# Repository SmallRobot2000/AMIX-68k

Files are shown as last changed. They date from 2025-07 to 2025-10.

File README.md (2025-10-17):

# AMIX-68k
This is my Motorola 68010 CPU based system.
I plan to make it with 68010 CPU @ 12Mhz, DMA(68450) and othere periferials @ 10Mhz, IDE disk (CF card or good old HDD), Video output (Xosera), Aduio output (Aslo Xosera), Timers (again Xosera and 68230), Keyboard (68230 with RC2014 Yellow series MSX style keyboard), UART (16550 @ 115200 bps)

This isn't my first or (hopefully)last Retro style computer system, I alredy made two 6502 based computers, 8088 based system that is IBM compatable with 8 bit ISA, and built and coded for a handfull of z80/z180 based systems, mostly two RC2014 (Its funny that i like z80 MUCH more than 6502 but never made a system araund z80).
And also have ZX Spectrum 48k and ZX Spectrum NEXT.

But somehow this is the first time working with 68k chip, I known for 68k style systems but was afraid to touch them because they are two times more complex thatn 8 bit(right?) especely when i made 8088 system that was 8/16 bit and coudnt think how complecated would a full 16 bit system be, but when i looked closer at Motorola 68000 i thought i steped in to heven because of all the documentation and datasheet, and how a SINGLE datasheet was enough to understand almost everything to know(looking at you Intel).

# SPECS

|CPU | Motorola 68010 @ 12Mhz|
|----|---|
|RAM | 2 MB SRAM (Maybe DRAM in future)
|DMA | 68450 @ 10 Mhz|
|VIDEO & AUDIO| Xosera 640x480 2 playfields and Copper ( ͡❛ ͜ʖ ͡❛)|
|Keyboard| RC2014 Yellow series MSX style keyboard with n key rollover|
|DISK| IDE interface CF card or clasic HDD|
|UART| 16550 @ 18.432 Mhz -> 115200 bps|
|POWER| ATX PSU or 12V in|
|TIME & TIMERS| Tmers in Xosera and 68230, and RTC (SparkFun BOB-10160)|

# Present
All important stuff in kernel is done, now its time to make a unix like shell inside the kernel, later I will make it a executable file
All executables are in ELF file format, scripts are not yet suported nether are pipes and redirects.
# Future (TODO)

 - Add working permissions and thus users
 - Shell as executable not built in kenrel
 - Support for pipes and redirects
 - Move keyboard to a new process and make it all in C because now it sometimes glitches
 - Clean up code and make more flexiable(cariables insted of defines)
 - Move some stuff to files like history and $PATH etc.
 - Add global sbrk with suport for freeing all alocations per process when killed
 - When poritng keyboard to C add some shortcuts
 - add system specific command something similar to symctl
 - add Ethernet as expantion

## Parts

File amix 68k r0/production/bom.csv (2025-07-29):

Designator | Footprint | Quantity | Value | LCSC Part #
C1 | CP_Radial_D5.0mm_P2.50mm | 1 | 10uF
C10, C11, C12, C13, C14, C15, C16, C17, C18, C21, C22, C23, C24, C25, C26, C27, C28, C29, C30, C31, C32, C8, C9 | C_Rect_L4.0mm_W2.5mm_P2.50mm | 23 | 100nF
C19 | CP_Radial_D5.0mm_P2.50mm | 1 | 100uF
C2 | C_Rect_L4.0mm_W2.5mm_P2.50mm | 1 | 1uF
C20 | CP_Radial_D6.3mm_P2.50mm | 1 | 220uF
C3, C5, C7 | CP_Radial_D5.0mm_P2.50mm | 3 | 10uF
C33, C4, C6 | CP_Radial_D5.0mm_P2.50mm | 3 | 1uF(2.2uF real)
D1, D2 | D_DO-35_SOD27_P7.62mm_Horizontal | 2 | D
D10 | LED_D4.0mm | 1 | LED_+5
D11 | LED_D4.0mm | 1 | LED_+5SB
D12 | LED_D4.0mm | 1 | LED_-12
D3, D4, D5, D6 | LED_D4.0mm | 4 | LED
D7, D8 | D_DO-35_SOD27_P7.62mm_Horizontal | 2 | 1N4148
D9 | LED_D4.0mm | 1 | LED_+12
HOLE1, HOLE2, HOLE3, HOLE4, HOLE5, HOLE6, HOLE7 | Hole_3mm | 7 | HOLE
IC1, IC2, IC3 | DIP-20_W7.62mm_Socket_LongPads | 3 | 74HCT245
J1 | PinHeader_1x03_P2.54mm_Vertical | 1 | BG
J10 | PinSocket_2x06_P2.54mm_Horizontal | 1 | PMOD_BOTTOM
J11, J12, J15, J27 | PinHeader_1x04_P2.54mm_Vertical | 4 | Conn_01x04_Pin
J13 | PinHeader_1x07_P2.54mm_Vertical | 1 | RTC (SparkFun BOB-10160)
J14 | USB_B_Lumberg_2411_02_Horizontal | 1 | USB_B
J16 | Molex_Mini-Fit_Jr_5566-24A2_2x12_P4.20mm_Vertical | 1 | ATX-24 - IF NO 12V in
J17 | BarrelJack_Horizontal | 1 | 12V in if NO ATX
J18 | IDC-Header_2x20_P2.54mm_Vertical | 1 | IDE 40 pin
J19 | PinHeader_1x02_P2.54mm_Vertical | 1 | ExtPWRON
J2 | PinHeader_1x03_P2.54mm_Vertical | 1 | FCx
J20 | PinHeader_1x02_P2.54mm_Vertical | 1 | PWR_LED
J21 | IDC-Header_2x08_P2.54mm_Vertical | 1 | Conn_02x08_Odd_Even
J22 | PinHeader_1x12_P2.54mm_Vertical | 1 | PPI
J23, J24 | PinHeader_1x08_P2.54mm_Vertical | 2 | Conn_01x08_Pin
J25, J26 | PinHeader_2x04_P2.54mm_Vertical | 2 | Conn_02x04_Odd_Even
J28 | PinSocket_2x32_P2.54mm_Horizontal | 1 | Conn_02x32_Odd_Even
J29 | PinHeader_1x02_P2.54mm_Vertical | 1 | NMI
J3 | PinHeader_1x03_P2.54mm_Vertical | 1 | PRF
J4 | PinHeader_1x02_P2.54mm_Vertical | 1 | BUS_STAT
J5 | PinHeader_1x02_P2.54mm_Vertical | 1 | HLT and RESET
J6 | PinHeader_1x24_P2.54mm_Vertical | 1 | Upduino_LHS
J7 | PinHeader_1x24_P2.54mm_Vertical | 1 | Upduino_RHS
J8 | PinHeader_1x06_P2.54mm_Vertical | 1 | Conn_01x06_Pin
J9 | PinSocket_2x06_P2.54mm_Horizontal | 1 | PMOD_TOP
JP1, JP2, JP21, JP8 | PinHeader_1x02_P2.54mm_Vertical | 4 | Jumper_2_Open
JP10, JP11 | PinHeader_1x02_P2.54mm_Vertical | 2 | Close only if NO ATX
JP14, JP15 | PinHeader_1x02_P2.54mm_Vertical | 2 | DTACK ctrl 0
JP16 | PinHeader_1x02_P2.54mm_Vertical | 1 | DMAAC_REQ0 = IDE
JP17 | PinHeader_1x02_P2.54mm_Vertical | 1 | DMAAC_ACK0 = IDE
JP18, JP20 | PinHeader_1x02_P2.54mm_Vertical | 2 | Jumper_2_Bridged
JP3, JP4, JP5, JP6 | PinHeader_1x02_P2.54mm_Vertical | 4 | Jumper
Q1, Q2 | TO-92_Inline | 2 | 2N3904
R1, R14, R15, R17, R2 | R_Axial_DIN0207_L6.3mm_D2.5mm_P10.16mm_Horizontal | 5 | 1k
R10, R11, R12, R5, R6, R7, R8, R9 | R_Axial_DIN0207_L6.3mm_D2.5mm_P10.16mm_Horizontal | 8 | 100
R13, R24 | R_Axial_DIN0207_L6.3mm_D2.5mm_P10.16mm_Horizontal | 2 | 150k
R16, R18, R19, R20, R21, R22, R3, R30, R4 | R_Axial_DIN0207_L6.3mm_D2.5mm_P10.16mm_Horizontal | 9 | 10k
R23 | R_Axial_DIN0207_L6.3mm_D2.5mm_P10.16mm_Horizontal | 1 | 470
R25, R26 | R_Axial_DIN0207_L6.3mm_D2.5mm_P10.16mm_Horizontal | 2 | 680
R27, R28, R29 | R_Axial_DIN0207_L6.3mm_D2.5mm_P10.16mm_Horizontal | 3 | 330
RN1, RN2, RN3, RN4 | R_Array_SIP8 | 4 | R_Network07
SW1 | SW_PUSH_6mm | 1 | Reset
SW3 | SW_Slide_SPDT_Angled_CK_OS102011MA1Q | 1 | SW_SPDT
U1 | DIP-64_W22.86mm_Socket_LongPads | 1 | MC68010P
U10, U11, U12, U3 | DIP-20_W7.62mm_Socket_LongPads | 4 | GAL16V8
U13 | DIP-40_W15.24mm_Socket_LongPads | 1 | 16550
U14 | SSOP-28_5.3x10.2mm_P0.65mm | 1 | FT232RL
U15 | TO-220-3_Horizontal_TabDown | 1 | LM7805_TO220
U16, U28 | DIP-14_W7.62mm_Socket_LongPads | 2 | 74HC74
U17 | TO-220-3_Horizontal_TabDown | 1 | LM1117T-3.3
U18 | DIP-64_W22.86mm_Socket_LongPads | 1 | MC68450
U19, U20, U21 | DIP-20_W7.62mm_Socket_LongPads | 3 | 74HC245
U2, U27 | DIP-14_W7.62mm_Socket_LongPads | 2 | 74HC14
U22, U23 | DIP-20_W7.62mm_Socket_LongPads | 2 | 74HC373
U24 | DIP-14_W7.62mm_Socket_LongPads | 1 | 74LS32
U25 | DIP-16_W7.62mm_Socket_LongPads | 1 | 74LS148
U26 | DIP-48_W15.24mm_Socket_LongPads | 1 | 68230
U4, U5, U6, U7 | DIP-32_W15.24mm_Socket_LongPads | 4 | AS6C4008-55PCN
U8, U9 | DIP_Socket-32_W11.9_W12.7_W15.24_W17.78_W18.5_3M_232-1285-00-0602J | 2 | SST39SF040
Y1 | Oscillator_DIP-14 | 1 | 1.8432Mhz
Y3 | Oscillator_DIP-14 | 1 | 12Mhz
Y5 | Oscillator_DIP-14 | 1 | 10Mhz
Mouser
Mix

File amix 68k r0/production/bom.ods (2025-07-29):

Designator | Footprint | Quantity | Value | Mouser Part # | Socket*
C1 | CP_Radial_D5.0mm_P2.50mm | 1 | 10uF | 667-ECA-1CM100I
C10, C11, C12, C13, C14, C15, C16, C17, C18, C21, C22, C23, C24, C25, C26, C27, C28, C29, C30, C31, C32, C8, C9 | C_Rect_L4.0mm_W2.5mm_P2.50mm | 23 | 100nF | 594-K104K15X7RF53L2
C19 | CP_Radial_D5.0mm_P2.50mm | 1 | 100uF | 667-ECA-0JM101I
C2 | C_Rect_L4.0mm_W2.5mm_P2.50mm | 1 | 1uF | 810-FG18X7R1E105KRT6
C20 | CP_Radial_D6.3mm_P2.50mm | 1 | 220uF | 667-EEU-FC1A221SB
C3, C5, C7 | CP_Radial_D5.0mm_P2.50mm | 3 | 10uF | 667-ECA-1CM100I
C33, C4, C6 | CP_Radial_D5.0mm_P2.50mm | 3 | 1uF(2.2uF real) | 667-ECA-1HHG2R2I
D1, D2 | D_DO-35_SOD27_P7.62mm_Horizontal | 2 | D | 512-1N4148
D10 | LED_D4.0mm | 1 | LED_+5 | 630-HLMP-LG75-XY0DD
D11 | LED_D4.0mm | 1 | LED_+5SB | 630-HLMP-LG75-XY0DD
D12 | LED_D4.0mm | 1 | LED_-12 | 630-HLMP-LG75-XY0DD
D3, D4, D5, D6 | LED_D4.0mm | 4 | LED | 630-HLMP-LB65-RU0DD
D7, D8 | D_DO-35_SOD27_P7.62mm_Horizontal | 2 | 1N4148 | 512-1N4148
D9 | LED_D4.0mm | 1 | LED_+12 | 630-HLMP-LG75-XY0DD
HOLE1, HOLE2, HOLE3, HOLE4, HOLE5, HOLE6, HOLE7 | Hole_3mm | 7 | HOLE | NaN
IC1, IC2, IC3 | DIP-20_W7.62mm_Socket_LongPads | 3 | 74HCT245 | 595-SN74HCT245N | 571-1-2199298-6
J1 | PinHeader_1x03_P2.54mm_Vertical | 1 | BG | 200-TSW14023TS
J10 | PinSocket_2x06_P2.54mm_Horizontal | 1 | PMOD_BOTTOM | 710-613012243121
J11, J12, J15, J27 | PinHeader_1x04_P2.54mm_Vertical | 4 | Conn_01x04_Pin | 200-TSW14023TS
J13 | PinHeader_1x07_P2.54mm_Vertical | 1 | RTC (SparkFun BOB-10160) | 710-61304011021 | 872-920-0215-01
J14 | USB_B_Lumberg_2411_02_Horizontal | 1 | USB_B | 179-UJ2-B-HR-G-TH
J16 | Molex_Mini-Fit_Jr_5566-24A2_2x12_P4.20mm_Vertical | 1 | ATX-24 - IF NO 12V in | 538-39-28-1243
J17 | BarrelJack_Horizontal | 1 | 12V in if NO ATX | 490-PJ-102A
J18 | IDC-Header_2x20_P2.54mm_Vertical | 1 | IDE 40 pin | 200-TST12003GD
J19 | PinHeader_1x02_P2.54mm_Vertical | 1 | ExtPWRON | 200-TSW14023TS
J2 | PinHeader_1x03_P2.54mm_Vertical | 1 | FCx | 200-TSW14023TS
J20 | PinHeader_1x02_P2.54mm_Vertical | 1 | PWR_LED | 200-TSW14023TS
J21 | IDC-Header_2x08_P2.54mm_Vertical | 1 | Conn_02x08_Odd_Even | 200-TST10802TD
J22 | PinHeader_1x12_P2.54mm_Vertical | 1 | PPI | 200-TSW14023TS
J23, J24 | PinHeader_1x08_P2.54mm_Vertical | 2 | Conn_01x08_Pin | 200-TSW14023TS
J25, J26 | PinHeader_2x04_P2.54mm_Vertical | 2 | Conn_02x04_Odd_Even | 523-G800LQ592032HR
J28 | PinSocket_2x32_P2.54mm_Horizontal | 1 | Conn_02x32_Odd_Even | 200-SSW13202TDRA
J29 | PinHeader_1x02_P2.54mm_Vertical | 1 | NMI | 200-TSW14023TS
J3 | PinHeader_1x03_P2.54mm_Vertical | 1 | PRF | 200-TSW14023TS
J4 | PinHeader_1x02_P2.54mm_Vertical | 1 | BUS_STAT | 200-TSW14023TS
J5 | PinHeader_1x02_P2.54mm_Vertical | 1 | HLT and RESET | 200-TSW14023TS
J6 | PinHeader_1x24_P2.54mm_Vertical | 1 | Upduino_LHS | 200-BCS124FSTE
J7 | PinHeader_1x24_P2.54mm_Vertical | 1 | Upduino_RHS | 200-BCS124FSTE
J8 | PinHeader_1x06_P2.54mm_Vertical | 1 | Conn_01x06_Pin | 200-TSW14023TS
J9 | PinSocket_2x06_P2.54mm_Horizontal | 1 | PMOD_TOP | 710-613012243121
JP1, JP2, JP21, JP8 | PinHeader_1x02_P2.54mm_Vertical | 4 | Jumper_2_Open | 200-TSW14023TS
JP10, JP11 | PinHeader_1x02_P2.54mm_Vertical | 2 | Close only if NO ATX | 200-TSW14023TS
JP14, JP15 | PinHeader_1x02_P2.54mm_Vertical | 2 | DTACK ctrl 0 | 200-TSW14023TS
JP16 | PinHeader_1x02_P2.54mm_Vertical | 1 | DMAAC_REQ0 = IDE | 200-TSW14023TS
JP17 | PinHeader_1x02_P2.54mm_Vertical | 1 | DMAAC_ACK0 = IDE | 200-TSW14023TS
JP18, JP20 | PinHeader_1x02_P2.54mm_Vertical | 2 | Jumper_2_Bridged | 200-TSW14023TS
JP3, JP4, JP5, JP6 | PinHeader_1x02_P2.54mm_Vertical | 4 | Jumper | 200-TSW14023TS
Q1, Q2 | TO-92_Inline | 2 | 2N3904 | 637-2N3904
R1, R14, R15, R17, R2 | R_Axial_DIN0207_L6.3mm_D2.5mm_P10.16mm_Horizontal | 5 | 1k | 603-MF0207FRE52-1K
R10, R11, R12, R5, R6, R7, R8, R9 | R_Axial_DIN0207_L6.3mm_D2.5mm_P10.16mm_Horizontal | 8 | 100 | 603-MF0207FRE52-100R
R13, R24 | R_Axial_DIN0207_L6.3mm_D2.5mm_P10.16mm_Horizontal | 2 | 150k | 603-MF0207FTE52-150K
R16, R18, R19, R20, R21, R22, R3, R30, R4 | R_Axial_DIN0207_L6.3mm_D2.5mm_P10.16mm_Horizontal | 9 | 10k | 603-MF0207FRE52-10K
R23 | R_Axial_DIN0207_L6.3mm_D2.5mm_P10.16mm_Horizontal | 1 | 470 | 603-MF0207FRE52-470R
R25, R26 | R_Axial_DIN0207_L6.3mm_D2.5mm_P10.16mm_Horizontal | 2 | 680 | 603-MF0207FTE52-680R
R27, R28, R29 | R_Axial_DIN0207_L6.3mm_D2.5mm_P10.16mm_Horizontal | 3 | 330 | 603-MF0207FTE52-330R
RN1, RN2, RN3, RN4 | R_Array_SIP8 | 4 | R_Network07 | 652-4608X-101-103FLF
SW1 | SW_PUSH_6mm | 1 | Reset | 179-TS026680BK100SCR
SW3 | SW_Slide_SPDT_Angled_CK_OS102011MA1Q | 1 | SW_SPDT | 611-OS102011MA1QN1
U1 | DIP-64_W22.86mm_Socket_LongPads | 1 | MC68010P |  | 575-199964
U10, U11, U12, U3 | DIP-20_W7.62mm_Socket_LongPads | 4 | GAL16V8 | 556-AF16V8B15PU | 571-1-2199298-6
U13 | DIP-40_W15.24mm_Socket_LongPads | 1 | 16550
U14 | SSOP-28_5.3x10.2mm_P0.65mm | 1 | FT232RL | 895-FT232RNL-REEL
U15 | TO-220-3_Horizontal_TabDown | 1 | LM7805_TO220 | 926-LM7805CT/NOPB
U16, U28 | DIP-14_W7.62mm_Socket_LongPads | 2 | 74HC74 | 595-SN74HC74N | 571-1-2199298-3
U17 | TO-220-3_Horizontal_TabDown | 1 | LM1117T-3.3 | 926-LM1117T-3.3/NOPB
U18 | DIP-64_W22.86mm_Socket_LongPads | 1 | MC68450 |  | 575-199964
U19, U20, U21 | DIP-20_W7.62mm_Socket_LongPads | 3 | 74HC245 | 595-SN74HC245N | 571-1-2199298-6
U2, U27 | DIP-14_W7.62mm_Socket_LongPads | 2 | 74HC14 | 595-SN74HCT14N | 571-1-2199298-3
U22, U23 | DIP-20_W7.62mm_Socket_LongPads | 2 | 74HC373 | 595-SN74HCT373N | 571-1-2199298-6
U24 | DIP-14_W7.62mm_Socket_LongPads | 1 | 74LS32 | 595-SN74HC32N | 571-1-2199298-3
U25 | DIP-16_W7.62mm_Socket_LongPads | 1 | 74LS148 | 595-SN74HC148N | 571-1-2199298-4
U26 | DIP-48_W15.24mm_Socket_LongPads | 1 | 68230 |  | 575-1104764841001000
U4, U5, U6, U7 | DIP-32_W15.24mm_Socket_LongPads | 4 | AS6C4008-55PCN | 913-AS6C4008-55PIN | 571-1-2199300-2
U8, U9 | DIP_Socket-32_W11.9_W12.7_W15.24_W17.78_W18.5_3M_232-1285-00-0602J | 2 | SST39SF040 | 804-39SF0407CPHE | 535-32-6570-10
Y1 | Oscillator_DIP-14 | 1 | 1.8432Mhz/18.432 | 774-MXO45HS-3C-12.0 |  | 815-ACO-18.432-EK
Y3 | Oscillator_DIP-14 | 1 | 12Mhz | 774-MXO45HS-3C-12.0 |  | 774-MXO45HS-3C-12.0, 520-TCF600-X
Y5 | Oscillator_DIP-14 | 1 | 10Mhz | 520-TCF1000-X |  | 520-TCF800-X
Mouser
Mix
Using old

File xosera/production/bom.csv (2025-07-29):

Designator | Footprint | Quantity | Value | LCSC Part #
C1, C10, C11, C2, C3, C4, C5, C6, C9 | C2.5-3 | 9 | 100nF
C7 | CP_Radial_D5.0mm_P2.50mm | 1 | 100uF
C8 | CP_Radial_D6.3mm_P2.50mm | 1 | 220uF
IC1, IC2, IC5 | DIP-20_W7.62mm_Socket_LongPads | 3 | 74HCT245
IC3 | DIP-20_W7.62mm_Socket_LongPads | 1 | ATF16V8BQL
IC4 | DIP-24_W7.62mm_LongPads | 1 | GAL22V10
IC6 | DIP-14_W7.62mm_Socket_LongPads | 1 | 74LS74
J1 | PinHeader_1x02_P2.54mm_Vertical | 1 | IOSEL/VPA
J2 | PinSocket_1x24_P2.54mm_Vertical | 1 | Upduino_LHS
J28 | PinSocket_2x32_P2.54mm_Horizontal | 1 | Conn_02x32_Odd_Even
J3 | PinSocket_1x24_P2.54mm_Vertical | 1 | Upduino_RHS
J4 | PinSocket_2x06_P2.54mm_Horizontal | 1 | PMOD_TOP
J5 | PinSocket_2x06_P2.54mm_Horizontal | 1 | PMOD_BOTTOM
J6 | PinHeader_1x06_P2.54mm_Vertical | 1 | Conn_01x06_Male
J7, J8 | PinHeader_2x04_P2.54mm_Vertical | 2 | Conn_02x04_Counter_Clockwise
JP1, JP3, JP4, JP5, JP6 | PinHeader_1x02_P2.54mm_Vertical | 5 | Jumper
JP2 | SolderJumper-2_P1.3mm_Open_Pad1.0x1.5mm | 1 | Jumper
JP7 | SolderJumper-2_P1.3mm_Open_Pad1.0x1.5mm | 1 | ~{IRQ5}
Q1 | TO-92_HandSolder | 1 | 2N3904
R1, R2, R3, R4, R5, R6, R7, R8 | R-0207_10 | 8 | R
R9 | R-0207_10 | 1 | 150K
TP1, TP2, TP3 | PinHeader_1x08_P2.54mm_Vertical | 3 | Conn_01x08_Male

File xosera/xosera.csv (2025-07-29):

Id | Designator | Package | Quantity | Designation | Supplier and ref
1 | J3 | PinSocket_1x24_P2.54mm_Vertical | 1 | Upduino_RHS
2 | IC4 | DIP-24_W7.62mm_LongPads | 1 | GAL22V10
3 | JP2 | SolderJumper-2_P1.3mm_Open_Pad1.0x1.5mm | 1 | Jumper
4 | REF** | MD-rosco_m68k_logo | 1 | MD-rosco_m68k_logo
5 | REF** | WEEE-Logo_4.2x6mm_SilkScreen | 1 | WEEE-Logo_4.2x6mm_SilkScreen
6 | REF** | RoHS-Logo_6mm_SilkScreen | 1 | RoHS-Logo_6mm_SilkScreen
7 | REF** | SM-rosco_m68k_logo | 1 | SM-rosco_m68k_logo
8 | J6 | PinHeader_1x06_P2.54mm_Vertical | 1 | Conn_01x06_Male
9 | JP6,JP5,JP4,JP3,JP1 | PinHeader_1x02_P2.54mm_Vertical | 5 | Jumper
10 | IC1,IC5,IC2 | DIP-20_W7.62mm_Socket_LongPads | 3 | 74HCT245
11 | Q1 | TO-92_HandSolder | 1 | 2N3904
12 | IC6 | DIP-14_W7.62mm_Socket_LongPads | 1 | 74LS74
13 | R9 | R-0207_10 | 1 | 150K
14 | J2 | PinSocket_1x24_P2.54mm_Vertical | 1 | Upduino_LHS
15 | TP3,TP2,TP1 | PinHeader_1x08_P2.54mm_Vertical | 3 | Conn_01x08_Male
16 | J1 | pin-2X32 | 1 | Conn_02x32_Odd_Even
17 | J5 | PinSocket_2x06_P2.54mm_Horizontal | 1 | PMOD_BOTTOM
18 | J4 | PinSocket_2x06_P2.54mm_Horizontal | 1 | PMOD_TOP
19 | C6,C11,C10,C9,C5,C4,C3,C2,C1 | C2.5-3 | 9 | 100nF
20 | R8,R7,R6,R5,R4,R3,R2,R1 | R-0207_10 | 8 | R
21 | J7,J8 | PinHeader_2x04_P2.54mm_Vertical | 2 | Conn_02x04_Counter_Clockwise
22 | IC3 | DIP-20_W7.62mm_Socket_LongPads | 1 | ATF16V8BQL
23 | C8 | CP_Radial_D6.3mm_P2.50mm | 1 | 220uF
24 | C7 | CP_Radial_D5.0mm_P2.50mm | 1 | 100uF

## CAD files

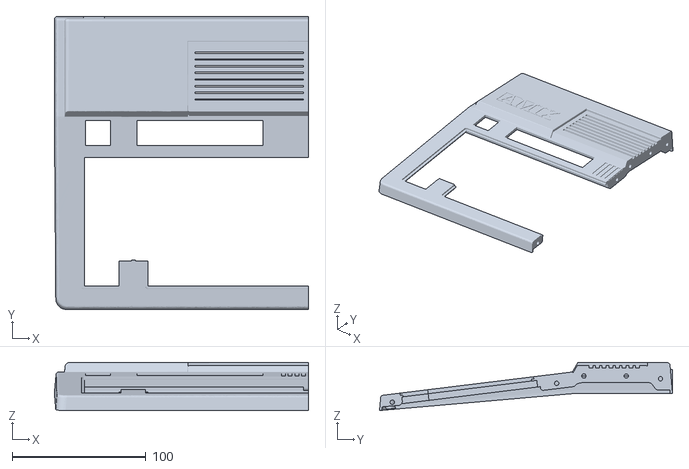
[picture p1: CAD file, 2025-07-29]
AMIX case/Top_left.stl
190.4 x 219.4 x 36.0

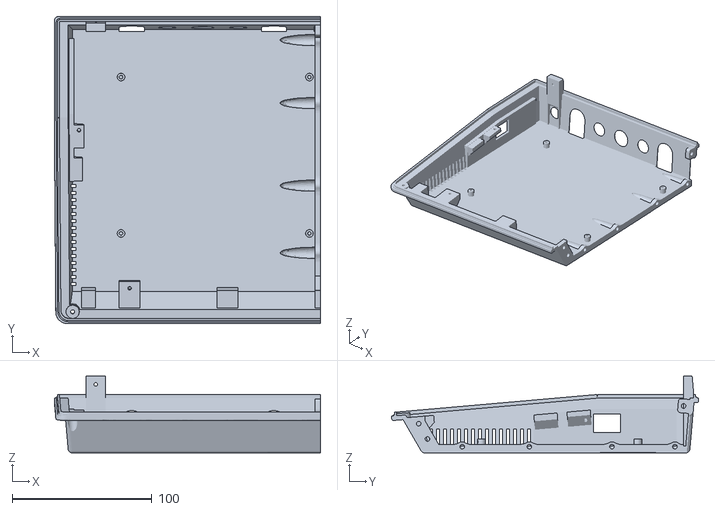
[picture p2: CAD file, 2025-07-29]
AMIX case/Bottom_left.stl
190.4 x 219.4 x 55.0

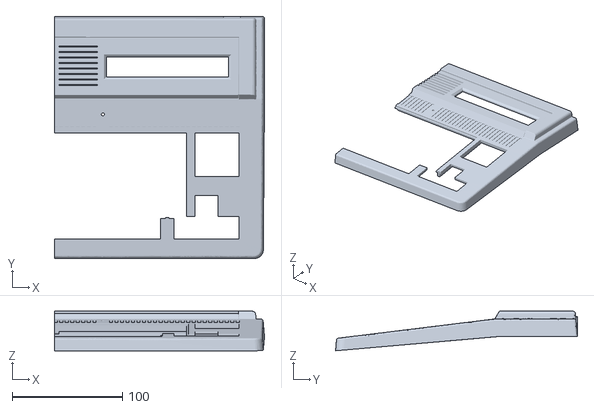
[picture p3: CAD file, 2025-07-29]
AMIX case/Top_right.stl
190.4 x 219.4 x 35.9

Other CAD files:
AMIX case/Bottom_right.stl

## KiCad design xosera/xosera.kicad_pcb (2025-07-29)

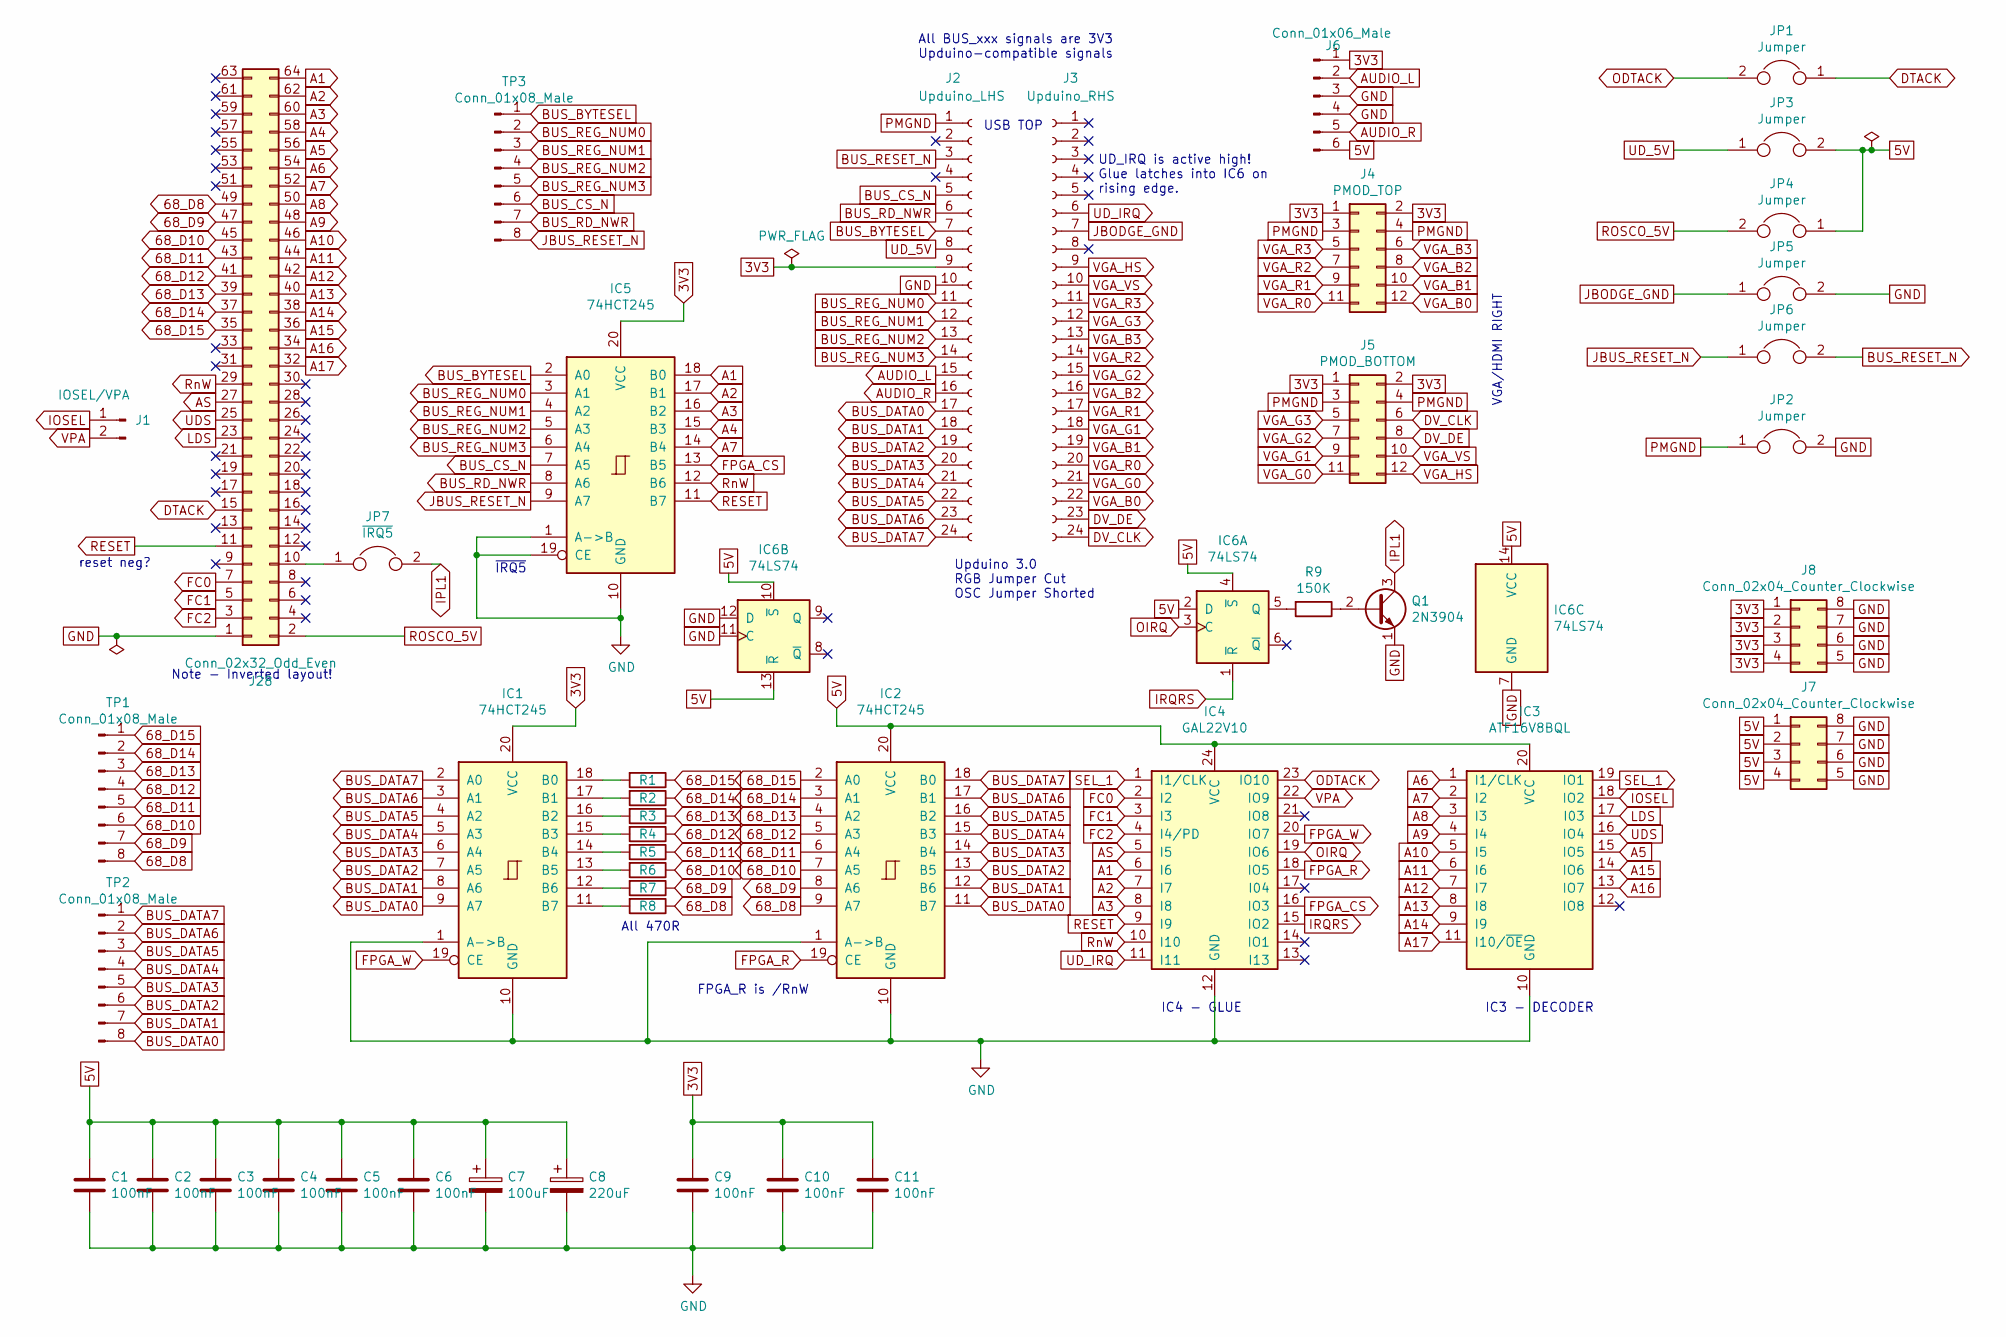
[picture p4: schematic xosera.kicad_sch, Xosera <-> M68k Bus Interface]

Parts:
C1, C2, C3, C4, C5, C6, C9, C10, C11: 100nF; C2.5-3
C7: 100uF; CP_Radial_D5.0mm_P2.50mm
C8: 220uF; CP_Radial_D6.3mm_P2.50mm
IC1, IC2, IC5: 74HCT245; DIP-20_W7.62mm_Socket_LongPads
IC3: ATF16V8BQL; DIP-20_W7.62mm_Socket_LongPads
IC4: GAL22V10; DIP-24_W7.62mm_LongPads
IC6: 74LS74; DIP-14_W7.62mm_Socket_LongPads
J1: IOSEL/VPA; PinHeader_1x02_P2.54mm_Vertical
J2: Upduino_LHS; PinSocket_1x24_P2.54mm_Vertical
J3: Upduino_RHS; PinSocket_1x24_P2.54mm_Vertical
J4: PMOD_TOP; PinSocket_2x06_P2.54mm_Horizontal
J5: PMOD_BOTTOM; PinSocket_2x06_P2.54mm_Horizontal
J6: Conn_01x06_Male; PinHeader_1x06_P2.54mm_Vertical
J7, J8: Conn_02x04_Counter_Clockwise; PinHeader_2x04_P2.54mm_Vertical
J28: Conn_02x32_Odd_Even; PinSocket_2x32_P2.54mm_Horizontal
JP1, JP3, JP4, JP5, JP6: Jumper; PinHeader_1x02_P2.54mm_Vertical
JP2: Jumper; SolderJumper-2_P1.3mm_Open_Pad1.0x1.5mm
JP7: ~{IRQ5}; SolderJumper-2_P1.3mm_Open_Pad1.0x1.5mm
Q1: 2N3904; TO-92_HandSolder
R1, R2, R3, R4, R5, R6, R7, R8: R; R-0207_10
R9: 150K; R-0207_10
TP1, TP2, TP3: Conn_01x08_Male; PinHeader_1x08_P2.54mm_Vertical

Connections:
3V3: C9.1, C10.1, C11.1, IC1.20 (VCC), IC5.20 (VCC), J2.9, J4.1, J4.2, J5.1, J5.2, J6.1, J8.1, J8.2, J8.3, J8.4
68_D8: IC2.9 (A7), J28.49, R8.1, TP1.8
68_D9: IC2.8 (A6), J28.47, R7.1, TP1.7
68_D10: IC2.7 (A5), J28.45, R6.1, TP1.6
68_D11: IC2.6 (A4), J28.43, R5.1, TP1.5
68_D12: IC2.5 (A3), J28.41, R4.1, TP1.4
68_D13: IC2.4 (A2), J28.39, R3.1, TP1.3
68_D14: IC2.3 (A1), J28.37, R2.1, TP1.2
68_D15: IC2.2 (A0), J28.35, R1.1, TP1.1
A1: IC4.6 (I6), IC5.18 (B0), J28.64
A2: IC4.7 (I7), IC5.17 (B1), J28.62
A3: IC4.8 (I8), IC5.16 (B2), J28.60
A4: IC5.15 (B3), J28.58
A5: IC3.15 (IO5), J28.56
A6: IC3.1 (I1/CLK), J28.54
A7: IC3.2 (I2), IC5.14 (B4), J28.52
A8: IC3.3 (I3), J28.50
A9: IC3.4 (I4), J28.48
A10: IC3.5 (I5), J28.46
A11: IC3.6 (I6), J28.44
A12: IC3.7 (I7), J28.42
A13: IC3.8 (I8), J28.40
A14: IC3.9 (I9), J28.38
A15: IC3.14 (IO6), J28.36
A16: IC3.13 (IO7), J28.34
A17: IC3.11 (I10/~OE), J28.32
AS: IC4.5 (I5), J28.27
AUDIO_L: J2.15, J6.2
AUDIO_R: J2.16, J6.5
BUS_BYTESEL: IC5.2 (A0), J2.7, TP3.1
BUS_CS_N: IC5.7 (A5), J2.5, TP3.6
BUS_DATA0: IC1.9 (A7), IC2.11 (B7), J2.17, TP2.8
BUS_DATA1: IC1.8 (A6), IC2.12 (B6), J2.18, TP2.7
BUS_DATA2: IC1.7 (A5), IC2.13 (B5), J2.19, TP2.6
BUS_DATA3: IC1.6 (A4), IC2.14 (B4), J2.20, TP2.5
BUS_DATA4: IC1.5 (A3), IC2.15 (B3), J2.21, TP2.4
BUS_DATA5: IC1.4 (A2), IC2.16 (B2), J2.22, TP2.3
BUS_DATA6: IC1.3 (A1), IC2.17 (B1), J2.23, TP2.2
BUS_DATA7: IC1.2 (A0), IC2.18 (B0), J2.24, TP2.1
BUS_RD_NWR: IC5.8 (A6), J2.6, TP3.7
BUS_REG_NUM0: IC5.3 (A1), J2.11, TP3.2
BUS_REG_NUM1: IC5.4 (A2), J2.12, TP3.3
BUS_REG_NUM2: IC5.5 (A3), J2.13, TP3.4
BUS_REG_NUM3: IC5.6 (A4), J2.14, TP3.5
BUS_RESET_N: J2.3, JP6.2
DTACK: J28.15, JP1.1
DV_CLK: J3.24, J5.6
DV_DE: J3.23, J5.8
FC0: IC4.2 (I2), J28.7
FC1: IC4.3 (I3), J28.5
FC2: IC4.4 (I4/PD), J28.3
FPGA_CS: IC4.16 (IO3), IC5.13 (B5)
FPGA_R: IC2.19 (CE), IC4.18 (IO5)
FPGA_W: IC1.19 (CE), IC4.20 (IO7)
IOSEL: IC3.18 (IO2), J1.1
IPL1: JP7.2, Q1.3 (C)
IRQRS: IC4.15 (IO2), IC6.1 (~R)
JBODGE_GND: J3.7, JP5.1
JBUS_RESET_N: IC5.9 (A7), JP6.1, TP3.8
LDS: IC3.17 (I03), J28.23
unnamed: IC1.18 (B0), R1.2
unnamed: IC1.17 (B1), R2.2
unnamed: IC1.16 (B2), R3.2
unnamed: IC1.15 (B3), R4.2
unnamed: IC1.14 (B4), R5.2
unnamed: IC1.13 (B5), R6.2
unnamed: IC1.12 (B6), R7.2
unnamed: IC1.11 (B7), R8.2
unnamed: IC6.5 (Q), R9.2
unnamed: J28.10, JP7.1
unnamed: Q1.2 (B), R9.1
ODTACK: IC4.23 (IO10), JP1.2
OIRQ: IC4.19 (IO6), IC6.3 (C)
PMGND: J2.1, J4.3, J4.4, J5.3, J5.4, JP2.1
RESET: IC4.9 (I9), IC5.11 (B7), J28.11
ROSCO_5V: J28.2, JP4.2
RnW: IC4.10 (I10), IC5.12 (B6), J28.29
SEL_1: IC3.19 (IO1), IC4.1 (I1/CLK)
UDS: IC3.16 (IO4), J28.25
UD_5V: J2.8, JP3.1
UD_IRQ: IC4.11 (I11), J3.6
VGA_B0: J3.22, J4.12
VGA_B1: J3.19, J4.10
VGA_B2: J3.16, J4.8
VGA_B3: J3.13, J4.6
VGA_G0: J3.21, J5.11
VGA_G1: J3.18, J5.9
VGA_G2: J3.15, J5.7
VGA_G3: J3.12, J5.5
VGA_HS: J3.9, J5.12
VGA_R0: J3.20, J4.11
VGA_R1: J3.17, J4.9
VGA_R2: J3.14, J4.7
VGA_R3: J3.11, J4.5
VGA_VS: J3.10, J5.10
VPA: IC4.22 (IO9), J1.2

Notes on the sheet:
All BUS_xxx signals are 3V3 Upduino-compatible signals
VGA/HDMI RIGHT
~{IRQ5}
USB TOP
IC3 - DECODER
FPGA_R is /RnW
All 470R
reset neg?
Note - Inverted layout!
UD_IRQ is active high! Glue latches into IC6 on rising edge.
Upduino 3.0 RGB Jumper Cut OSC Jumper Shorted
IC4 - GLUE

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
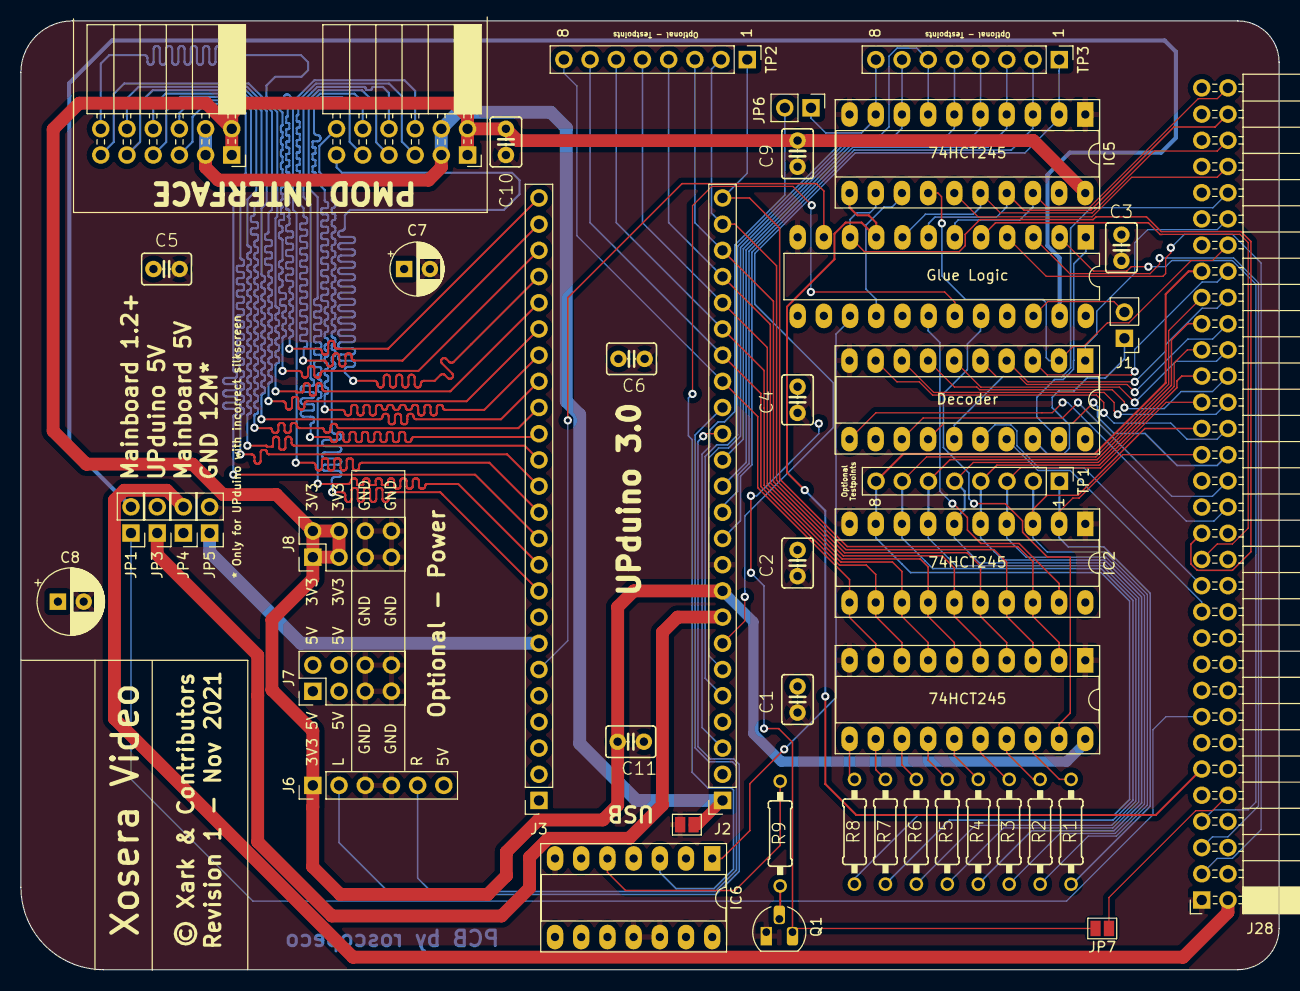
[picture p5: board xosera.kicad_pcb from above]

Board: 4 copper layers, 122.0 x 92.0 mm, 46 parts (0 on the bottom side), 98 nets.

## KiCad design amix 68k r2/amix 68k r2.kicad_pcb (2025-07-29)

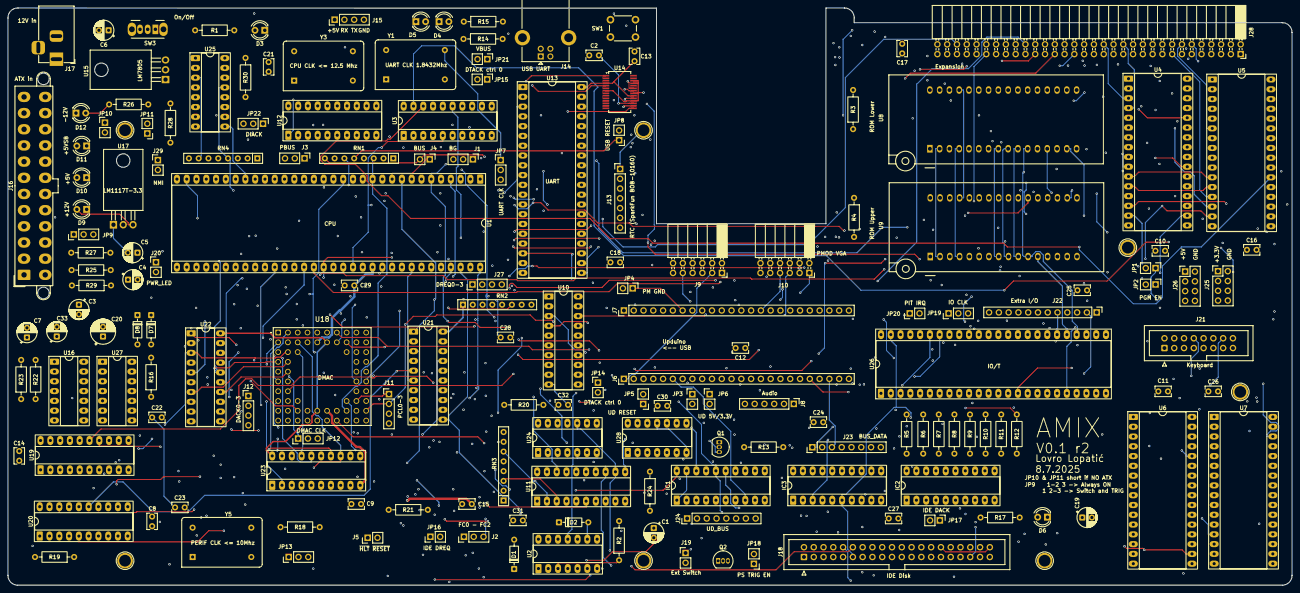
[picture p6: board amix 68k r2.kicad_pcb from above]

Board: 4 copper layers, 333.4 x 149.9 mm, 175 parts (0 on the bottom side), 269 nets.

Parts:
C1: C_Polarized; CP_Radial_D5.0mm_P2.50mm
C2: 1uF; C_Rect_L4.0mm_W2.5mm_P2.50mm
C3, C5, C7: 10uF; CP_Radial_D5.0mm_P2.50mm
C4, C6, C33: 1uF; CP_Radial_D5.0mm_P2.50mm
C8, C9, C10, C11, C12, C13, C14, C15, C16, C17, C18, C21, C22, C23, C24, C25, C26, C27, C28, C29, C30, C31, C32: 100nF; C_Rect_L4.0mm_W2.5mm_P2.50mm
C19: 100uF; CP_Radial_D5.0mm_P2.50mm
C20: 220uF; CP_Radial_D6.3mm_P2.50mm
D1, D2: D; D_DO-35_SOD27_P7.62mm_Horizontal
D3, D4, D5, D6: LED; LED_D4.0mm
D7, D8: 1N4148; D_DO-35_SOD27_P7.62mm_Horizontal
D9: LED_+12; LED_D4.0mm
D10: LED_+5; LED_D4.0mm
D11: LED_+5SB; LED_D4.0mm
D12: LED_-12; LED_D4.0mm
HOLE1, HOLE2, HOLE3, HOLE4, HOLE5, HOLE6, HOLE7: HOLE; Hole_3mm
IC1, IC2, IC3: 74HCT245; DIP-20_W7.62mm_Socket_LongPads
J1: BG; PinHeader_1x03_P2.54mm_Vertical
J2: FCx; PinHeader_1x03_P2.54mm_Vertical
J3: PRF; PinHeader_1x03_P2.54mm_Vertical
J4: BUS_STAT; PinHeader_1x02_P2.54mm_Vertical
J5: HLT and RESET; PinHeader_1x02_P2.54mm_Vertical
J6: Upduino_LHS; PinHeader_1x24_P2.54mm_Vertical
J7: Upduino_RHS; PinHeader_1x24_P2.54mm_Vertical
J8: Conn_01x06_Pin; PinHeader_1x06_P2.54mm_Vertical
J9: PMOD_TOP; PinSocket_2x06_P2.54mm_Horizontal
J10: PMOD_BOTTOM; PinSocket_2x06_P2.54mm_Horizontal
J11, J12, J15, J27: Conn_01x04_Pin; PinHeader_1x04_P2.54mm_Vertical
J13: RTC (SparkFun BOB-10160); PinHeader_1x07_P2.54mm_Vertical
J14: USB_B; USB_B_Lumberg_2411_02_Horizontal
J16: ATX-24 - IF NO 12V in; Molex_Mini-Fit_Jr_5566-24A2_2x12_P4.20mm_Vertical
J17: 12V in if NO ATX; BarrelJack_Horizontal
J18: IDE 40 pin; IDC-Header_2x20_P2.54mm_Vertical
J19: ExtPWRON; PinHeader_1x02_P2.54mm_Vertical
J20: PWR_LED; PinHeader_1x02_P2.54mm_Vertical
J21: Conn_02x08_Odd_Even; IDC-Header_2x08_P2.54mm_Vertical
J22: PPI; PinHeader_1x12_P2.54mm_Vertical
J23, J24: Conn_01x08_Pin; PinHeader_1x08_P2.54mm_Vertical
J25, J26: Conn_02x04_Odd_Even; PinHeader_2x04_P2.54mm_Vertical
J28: Conn_02x32_Odd_Even; PinSocket_2x32_P2.54mm_Horizontal
J29: NMI; PinHeader_1x02_P2.54mm_Vertical
JP1, JP2, JP8, JP21: Jumper_2_Open; PinHeader_1x02_P2.54mm_Vertical
JP3, JP4, JP5, JP6: Jumper; PinHeader_1x02_P2.54mm_Vertical
JP7, JP19, JP22: Jumper_3_Bridged12; PinHeader_1x03_P2.54mm_Vertical
JP9: 1-2 3 - > Always ON, 1 2-3 -> Enabled On/Off; PinHeader_1x03_P2.54mm_Vertical
JP10, JP11: Close only if NO ATX; PinHeader_1x02_P2.54mm_Vertical
JP12: DMAC CLK; PinHeader_1x03_P2.54mm_Vertical
JP13: DTACK_Pull UP/DOWN; PinHeader_1x03_P2.54mm_Vertical
JP14, JP15: DTACK ctrl 0; PinHeader_1x02_P2.54mm_Vertical
JP16: DMAAC_REQ0 = IDE; PinHeader_1x02_P2.54mm_Vertical
JP17: DMAAC_ACK0 = IDE; PinHeader_1x02_P2.54mm_Vertical
JP18, JP20: Jumper_2_Bridged; PinHeader_1x02_P2.54mm_Vertical
Q1, Q2: 2N3904; TO-92_Inline
R1, R2, R14, R15, R17: 1k; R_Axial_DIN0207_L6.3mm_D2.5mm_P10.16mm_Horizontal
R3, R4, R16, R18, R19, R20, R21, R22, R30: 10k; R_Axial_DIN0207_L6.3mm_D2.5mm_P10.16mm_Horizontal
R5, R6, R7, R8, R9, R10, R11, R12: R; R_Axial_DIN0207_L6.3mm_D2.5mm_P10.16mm_Horizontal
R13, R24: 150k; R_Axial_DIN0207_L6.3mm_D2.5mm_P10.16mm_Horizontal
R23: 470; R_Axial_DIN0207_L6.3mm_D2.5mm_P10.16mm_Horizontal
R25, R26: 680; R_Axial_DIN0207_L6.3mm_D2.5mm_P10.16mm_Horizontal
R27, R28, R29: 330; R_Axial_DIN0207_L6.3mm_D2.5mm_P10.16mm_Horizontal
RN1, RN2, RN3, RN4: R_Network07; R_Array_SIP8
SW1: Reset; SW_PUSH_6mm
SW3: SW_SPDT; SW_Slide_SPDT_Angled_CK_OS102011MA1Q
U1: MC68010P; DIP-64_W22.86mm_Socket_LongPads
U2, U27: 74HC14; DIP-14_W7.62mm_Socket_LongPads
U3, U10, U11, U12: GAL16V8; DIP-20_W7.62mm_Socket_LongPads
U4, U5, U6, U7: AS6C4008-55PCN; DIP-32_W15.24mm_Socket_LongPads
U8, U9: SST39SF040; DIP_Socket-32_W11.9_W12.7_W15.24_W17.78_W18.5_3M_232-1285-0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
U13: 16550; DIP-40_W15.24mm_Socket_LongPads
U14: FT232RL; SSOP-28_5.3x10.2mm_P0.65mm
U15: LM7805_TO220; TO-220-3_Horizontal_TabDown
U16, U28: 74HC74; DIP-14_W7.62mm_Socket_LongPads
U17: LM1117T-3.3; TO-220-3_Horizontal_TabDown
U18: 68 pin PGA socket 5108306810061101
U19, U20, U21: 74HC245; DIP-20_W7.62mm_Socket_LongPads
U22, U23: 74HC373; DIP-20_W7.62mm_Socket_LongPads
U24: 74LS32; DIP-14_W7.62mm_Socket_LongPads
U25: 74LS148; DIP-16_W7.62mm_Socket_LongPads
U26: 68230; DIP-48_W15.24mm_Socket_LongPads
Y1: 1.8432Mhz; Oscillator_DIP-14
Y3: 12Mhz; Oscillator_DIP-14
Y5: 10Mhz; Oscillator_DIP-14

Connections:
+3.3V: C21.1, C22.1, C23.1, IC1.20 (VCC), IC2.20 (VCC), J8.1, J9.1, J9.2, J10.1, J10.2, J16.1 (+3.3V), J16.2 (+3.3V), J16.12 (+3.3V), J16.13 (+3.3V), J25.1, J25.3, J25.5, J25.7, JP6.2 (B), JP10.1 (A)
+5V: C8.1, C9.1, C10.1, C11.1, C12.1, C13.1, C14.1, C15.1, C16.1, C17.1, C18.1, C19.1, C20.1, C24.1, C25.1, C26.1, C27.1, C28.1, C29.1, C30.1, C31.1, C32.1, D10.2 (A), IC3.20 (VCC), J8.6, J13.2, J15.1, J16.4 (+5V), J16.6 (+5V), J16.21 (+5V), J16.22 (+5V), J16.23 (+5V), J18.20, J18.38, J20.2, J21.2, J26.1, J26.3, J26.5, J26.7, J28.64, JP3.2 (B), JP11.1 (A), JP13.3 (B), JP21.2 (B), R1.1, R2.2, R3.2, R4.2, R14.2, R15.2, R17.2, R19.2, R20.2, R21.2, R30.2, RN1.1 (common), RN2.1 (common), RN3.1 (common), RN4.1 (common), U1.14 (V_{CC}), U1.49 (V_{CC}), U2.14 (VCC), U3.20 (VCC), U4.32 (VCC), U5.32 (VCC), U6.32 (VCC), U7.32 (VCC), U8.32 (VCC), U9.32 (VCC), U10.20 (VCC), U11.20 (VCC), U12.20 (VCC), U13.12 (CS0), U13.13 (CS1), U13.40 (VCC), U14.4 (VCCIO), U14.20 (VCC), U18.B6 (VCC), U18.J5 (Vcc), U19.20 (VCC), U20.20 (VCC), U21.20 (VCC), U22.20 (VCC), U23.20 (VCC), U24.14 (VCC), U25.16 (VCC), U26.12 (VCC), U28.1 (~R), U28.2 (D), U28.4 (~S), U28.10 (~S), U28.13 (~R), U28.14 (VCC), Y1.14 (Vcc), Y3.14 (Vcc), Y5.14 (Vcc)
+5VSB: D7.1 (K), D8.1 (K), D11.2 (A), J16.9 (+5VSB), R16.1, R22.1, U16.1 (~R), U16.10 (~S), U16.11 (C), U16.12 (D), U16.13 (~R), U16.14 (VCC), U27.9, U27.11, U27.13, U27.14 (VCC)
+12V: C3.1, C5.1, D9.2 (A), J16.10 (+12V), J16.11 (+12V), J17.1, J28.60, U15.1 (VI), U17.3 (VI)
-12V: D12.1 (K), J16.14 (-12V), J28.62
/UART + RTC + IDE/~IDE_LED: D6.1 (K), J18.39
A0: IC1.18 (B0), U10.15 (IO5)
A1: IC1.17 (B1), J18.35, J28.2, U1.29 (A1), U4.12 (A0), U5.12 (A0), U6.12 (A0), U7.12 (A0), U8.12 (A0), U9.12 (A0), U10.5 (I5), U13.28 (A0), U18.C8 (A1), U26.29 (RS1)
A2: IC1.16 (B2), J18.33, J28.4, U1.30 (A2), U4.11 (A1), U5.11 (A1), U6.11 (A1), U7.11 (A1), U8.11 (A1), U9.11 (A1), U13.27 (A1), U18.B8 (A2), U26.28 (RS2)
A3: IC1.15 (B3), J18.36, J28.6, U1.31 (A3), U4.10 (A2), U5.10 (A2), U6.10 (A2), U7.10 (A2), U8.10 (A2), U9.10 (A2), U13.26 (A2), U18.A9 (A3), U26.27 (RS3)
A4: IC1.14 (B4), J28.8, U1.32 (A4), U4.9 (A3), U5.9 (A3), U6.9 (A3), U7.9 (A3), U8.9 (A3), U9.9 (A3), U18.B7 (A4), U26.26 (RS4)
A5: J28.10, U1.33 (A5), U4.8 (A4), U5.8 (A4), U6.8 (A4), U7.8 (A4), U8.8 (A4), U9.8 (A4), U18.A8 (A5), U26.25 (RS5)
A6: J28.12, U1.34 (A6), U4.7 (A5), U5.7 (A5), U6.7 (A5), U7.7 (A5), U8.7 (A5), U9.7 (A5), U18.A7 (A6)
A7: J28.14, U1.35 (A7), U4.6 (A6), U5.6 (A6), U6.6 (A6), U7.6 (A6), U8.6 (A6), U9.6 (A6), U18.A6 (A7)
A8: J28.16, U1.36 (A8), U4.5 (A7), U5.5 (A7), U6.5 (A7), U7.5 (A7), U8.5 (A7), U9.5 (A7), U23.2 (O0)
A9: J28.18, U1.37 (A9), U4.27 (A8), U5.27 (A8), U6.27 (A8), U7.27 (A8), U8.27 (A8), U9.27 (A8), U23.5 (O1)
A10: J28.20, U1.38 (A10), U4.26 (A9), U5.26 (A9), U6.26 (A9), U7.26 (A9), U8.26 (A9), U9.26 (A9), U23.6 (O2)
A11: J28.22, U1.39 (A11), U4.23 (A10), U5.23 (A10), U6.23 (A10), U7.23 (A10), U8.23 (A10), U9.23 (A10), U23.9 (O3)
A12: J28.24, U1.40 (A12), U4.25 (A11), U5.25 (A11), U6.25 (A11), U7.25 (A11), U8.25 (A11), U9.25 (A11), U11.5 (I5), U23.12 (O4)
A13: J28.26, U1.41 (A13), U4.4 (A12), U5.4 (A12), U6.4 (A12), U7.4 (A12), U8.4 (A12), U9.4 (A12), U11.6 (I6), U23.15 (O5)
A14: J28.28, U1.42 (A14), U4.28 (A13), U5.28 (A13), U6.28 (A13), U7.28 (A13), U8.28 (A13), U9.28 (A13), U11.7 (I7), U23.16 (O6)
A15: J28.30, U1.43 (A15), U4.3 (A14), U5.3 (A14), U6.3 (A14), U7.3 (A14), U8.29 (A14), U9.29 (A14), U11.8 (I8), U23.19 (O7)
A16: J28.32, U1.44 (A16), U4.31 (A15), U5.31 (A15), U6.31 (A15), U7.31 (A15), U8.3 (A15), U9.3 (A15), U11.9 (I9), U22.2 (O0)
A17: J28.34, U1.45 (A17), U4.2 (A16), U5.2 (A16), U6.2 (A16), U7.2 (A16), U8.2 (A16), U9.2 (A16), U11.11 (I10/~OE), U22.5 (O1)
A18: J28.36, U1.46 (A18), U3.1 (I1/CLK), U4.30 (A17), U5.30 (A17), U6.30 (A17), U7.30 (A17), U8.30 (A17), U9.30 (A17), U22.6 (O2)
A19: J28.38, U1.47 (A19), U3.2 (I2), U4.1 (A18), U5.1 (A18), U6.1 (A18), U7.1 (A18), U8.1 (A18), U9.1 (A18), U22.9 (O3)
A20: J28.40, U1.48 (A20), U3.3 (I3), U22.12 (O4)
A21: J28.42, U1.50 (A21), U3.4 (I4), U22.15 (O5)
A22: J28.44, U1.51 (A22), U3.5 (I5), U22.16 (O6)
A23: J28.46, U1.52 (A23), U3.6 (I6), U22.19 (O7)
AUDIO_L: J6.15, J8.5
AUDIO_R: J6.16, J8.2
BUS_BYTESEL: IC1.2 (A0), J6.7, J24.1
BUS_CS_N: IC1.7 (A5), J6.5, J24.6
BUS_DATA0: IC2.9 (A7), IC3.11 (B7), J6.17, J23.8
BUS_DATA1: IC2.8 (A6), IC3.12 (B6), J6.18, J23.7
BUS_DATA2: IC2.7 (A5), IC3.13 (B5), J6.19, J23.6
BUS_DATA3: IC2.6 (A4), IC3.14 (B4), J6.20, J23.5
BUS_DATA4: IC2.5 (A3), IC3.15 (B3), J6.21, J23.4
BUS_DATA5: IC2.4 (A2), IC3.16 (B2), J6.22, J23.3
BUS_DATA6: IC2.3 (A1), IC3.17 (B1), J6.23, J23.2
BUS_DATA7: IC2.2 (A0), IC3.18 (B0), J6.24, J23.1
BUS_RD_NWR: IC1.8 (A6), J6.6, J24.7
BUS_REG_NUM0: IC1.3 (A1), J6.11, J24.2
BUS_REG_NUM1: IC1.4 (A2), J6.12, J24.3
BUS_REG_NUM2: IC1.5 (A3), J6.13, J24.4
BUS_REG_NUM3: IC1.6 (A4), J6.14, J24.5
BUS_RESET_N: J6.3, JP5.2 (B)
CLK: J28.31, JP12.3 (B), JP19.3 (B), U1.15 (CLK), Y3.8 (OUT)
D0: J18.4, U1.5 (D0), U4.13 (DQ0), U6.13 (DQ0), U8.13 (D0), U19.18 (B0), U21.18 (B0)
D1: J18.6, J28.1, U1.4 (D1), U4.14 (DQ1), U6.14 (DQ1), U8.14 (D1), U19.17 (B1), U21.17 (B1)
D2: J18.8, J28.3, U1.3 (D2), U4.15 (DQ2), U6.15 (DQ2), U8.15 (D2), U19.16 (B2), U21.16 (B2)
D3: J18.10, J28.5, U1.2 (D3), U4.17 (DQ3), U6.17 (DQ3), U8.17 (D3), U19.15 (B3), U21.15 (B3)
D4: J18.12, J28.7, U1.1 (D4), U4.18 (DQ4), U6.18 (DQ4), U8.18 (D4), U19.14 (B4), U21.14 (B4)
D5: J18.14, J28.9, U1.64 (D5), U4.19 (DQ5), U6.19 (DQ5), U8.19 (D5), U19.13 (B5), U21.13 (B5)
D6: J18.16, J28.11, U1.63 (D6), U4.20 (DQ6), U6.20 (DQ6), U8.20 (D6), U19.12 (B6), U21.12 (B6)
D7: J18.18, J28.13, U1.62 (D7), U4.21 (DQ7), U6.21 (DQ7), U8.21 (D7), U19.11 (B7), U21.11 (B7)
D8: IC3.9 (A7), J18.17, J28.15, R12.2, U1.61 (D8), U5.13 (DQ0), U7.13 (DQ0), U9.13 (D0), U13.1 (D0), U20.18 (B0), U21.2 (A0), U26.44 (D0)
D9: IC3.8 (A6), J18.15, J28.17, R11.2, U1.60 (D9), U5.14 (DQ1), U7.14 (DQ1), U9.14 (D1), U13.2 (D1), U20.17 (B1), U21.3 (A1), U26.45 (D1)
D10: IC3.7 (A5), J18.13, J28.19, R10.2, U1.59 (D10), U5.15 (DQ2), U7.15 (DQ2), U9.15 (D2), U13.3 (D2), U20.16 (B2), U21.4 (A2), U26.46 (D2)
D11: IC3.6 (A4), J18.11, J28.21, R9.2, U1.58 (D11), U5.17 (DQ3), U7.17 (DQ3), U9.17 (D3), U13.4 (D3), U20.15 (B3), U21.5 (A3), U26.47 (D3)
D12: IC3.5 (A3), J18.9, J28.23, R8.2, U1.57 (D12), U5.18 (DQ4), U7.18 (DQ4), U9.18 (D4), U13.5 (D4), U20.14 (B4), U21.6 (A4), U26.48 (D4)
D13: IC3.4 (A2), J18.7, J28.25, R7.2, U1.56 (D13), U5.19 (DQ5), U7.19 (DQ5), U9.19 (D5), U13.6 (D5), U20.13 (B5), U21.7 (A5), U26.1 (D5)
D14: IC3.3 (A1), J18.5, J28.27, R6.2, U1.55 (D14), U5.20 (DQ6), U7.20 (DQ6), U9.20 (D6), U13.7 (D6), U20.12 (B6), U21.8 (A6), U26.2 (D6)
D15: IC3.2 (A0), J18.3, J28.29, R5.2, U1.54 (D15), U5.21 (DQ7), U7.21 (DQ7), U9.21 (D7), U13.8 (D7), U20.11 (B7), U21.9 (A7), U26.3 (D7)
DMAC_A8/D0: U18.A5 (A8/D0), U19.2 (A0), U23.3 (D0)
DMAC_A9/D1: U18.B4 (A9/D1), U19.3 (A1), U23.4 (D1)
DMAC_A10/D2: U18.A4 (A10/D2), U19.4 (A2), U23.7 (D2)
DMAC_A11/D3: U18.A3 (A11/D3), U19.5 (A3), U23.8 (D3)
DMAC_A12/D4: U18.B3 (A12/D4), U19.6 (A4), U23.13 (D4)
DMAC_A13/D5: U18.A2 (A13/D5), U19.7 (A5), U23.14 (D5)
DMAC_A14/D6: U18.C3 (A14/D6), U19.8 (A6), U23.17 (D6)
DMAC_A15/D7: U18.B2 (A15/D7), U19.9 (A7), U23.18 (D7)
DMAC_A16/D8: U18.C2 (A16/D8), U20.2 (A0), U22.3 (D0)
DMAC_A17/D9: U18.B1 (A17/D9), U20.3 (A1), U22.4 (D1)
DMAC_A18/D10: U18.D2 (A18/D10), U20.4 (A2), U22.7 (D2)
DMAC_A19/D11: U18.C1 (A19/D11), U20.5 (A3), U22.8 (D3)
DMAC_A20/D12: U18.D1 (A20/D12), U20.6 (A4), U22.13 (D4)
DMAC_A21/D13: U18.E2 (A21/D13), U20.7 (A5), U22.14 (D5)
DMAC_A22/D14: U18.E1 (A22/D14), U20.8 (A6), U22.17 (D6)
DMAC_A23/D15: U18.F1 (A23/D15), U20.9 (A7), U22.18 (D7)
DMAC_PCL0: J11.1, U18.H9 (PCL0)
DMAC_PCL1: J11.2, J28.54, U18.J10 (PCL1)
DMAC_PCL2: J11.3, U18.G9 (PCL2)
DMAC_PCL3: J11.4, U18.H10 (PCL3)
DV_CLK: J7.24, J10.6
DV_DE: J7.23, J10.8
E: J3.2, J28.55, U1.20 (E)
FC0: J2.1, J28.57, U1.28 (FC0), U12.5 (I5), U18.F2 (FC0)
FC1: J2.2, J28.59, U1.27 (FC1), U12.6 (I6), U18.G1 (FC1)
FC2: J2.3, J28.61, U1.26 (FC2), U12.7 (I7), U18.H1 (FC2)
GND: C1.2, C2.1, C3.2, C4.2, C5.2, C6.2, C7.2, C8.2, C9.2, C10.2, C11.2, C12.2, C13.2, C14.2, C15.2, C16.2, C17.2, C18.2, C19.2, C20.2, C21.2, C22.2, C23.2, C24.2, C25.2, C26.2, C27.2, C28.2, C29.2, C30.2, C31.2, C32.2, C33.2, HOLE1.1, HOLE2.1, HOLE3.1, HOLE4.1, HOLE5.1, HOLE6.1, HOLE7.1, IC1.1 (A->B), IC1.10 (GND), IC1.19 (CE), IC2.1 (A->B), IC2.10 (GND), IC3.1 (A->B), IC3.10 (GND), J6.10, J8.3, J8.4, J13.1, J14.4 (GND), J14.5 (Shield), J15.4, J16.3 (GND), J16.5 (GND), J16.7 (GND), J16.15 (GND), J16.17 (GND), J16.18 (GND), J16.19 (GND), J16.24 (GND), J17.2, J17.3, J18.2, J18.19, J18.22, J18.24, J18.26, J18.30, J18.40, J19.2, J21.16, J25.2, J25.4, J25.6, J25.8, J26.2, J26.4, J26.6, J26.8, J28.63, J29.2, JP4.2 (B), JP9.1 (A), JP13.1 (A), Q1.1 (E), Q2.1 (E), R25.2, R26.2, R27.2, R28.2, R29.2, SW1.2, SW3.2 (B), U1.16 (GND), U1.53 (GND), U2.7 (GND), U3.10 (GND), U4.16 (VSS), U5.16 (VSS), U6.16 (VSS), U7.16 (VSS), U8.16 (GND), U9.16 (GND), U10.10 (GND), U11.10 (GND), U12.10 (GND), U13.19 (WR), U13.20 (GND), U13.22 (RD), U13.25 (~ADS), U14.7 (GND), U14.18 (GND), U14.21 (GND), U14.25 (AGND), U14.26 (TEST), U15.2 (GND), U16.7 (GND), U17.1 (GND), U18.B5 (GND), U18.J6 (GND), U19.10 (GND), U20.10 (GND), U21.10 (GND), U22.10 (GND), U23.10 (GND), U24.7 (GND), U25.5 (EI), U25.8 (GND), U26.38 (GND), U27.7 (GND), U28.7 (GND), U28.11 (C), U28.12 (D), Y1.7 (GND), Y3.7 (GND), Y5.7 (GND)
IO/~M: U3.13 (IO7), U11.1 (I1/CLK)
IRQ_UART: U2.11, U13.30 (INTR)
JBODGE_GND: J7.7, JP4.1 (A)
JBUS_RESET_N: IC1.9 (A7), J24.8, JP5.1 (A)
KYBD_CAPS_LED: J21.12, U26.21 (PB4)
KYBD_CODE_LED: J21.14, U26.22 (PB5)
KYBD_COL_0: J21.1, U26.4 (PA0)
KYBD_COL_1: J21.3, U26.5 (PA1)
KYBD_COL_2: J21.5, U26.6 (PA2)
KYBD_COL_3: J21.7, U26.7 (PA3)
KYBD_COL_4: J21.9, U26.8 (PA4)
KYBD_COL_5: J21.11, U26.9 (PA5)
KYBD_COL_6: J21.13, U26.10 (PA6)
KYBD_COL_7: J21.15, U26.11 (PA7)
KYBD_ROW_A: J21.4, U26.17 (PB0)
KYBD_ROW_B: J21.6, U26.18 (PB1)
KYBD_ROW_C: J21.8, U26.19 (PB2)
KYBD_ROW_D: J21.10, U26.20 (PB3)
unnamed: C1.1, R2.1, SW1.1, U2.3
unnamed: D1.1 (K), D2.1 (K), U2.2
unnamed: D3.2 (A), R1.2
unnamed: D4.2 (A), R14.1
unnamed: D4.1 (K), U14.23 (CBUS0)
unnamed: D5.2 (A), R15.1
unnamed: D5.1 (K), U14.22 (CBUS1)
unnamed: D6.2 (A), R17.1
unnamed: C7.1, D7.2 (A), R16.2, U27.3
unnamed: C33.1, D8.2 (A), R23.2, U27.1
unnamed: D9.1 (K), R25.1
unnamed: D10.1 (K), R27.1
unnamed: D11.1 (K), R28.1
unnamed: D12.2 (A), R26.1
unnamed: IC2.18 (B0), R5.1
unnamed: IC2.17 (B1), R6.1
unnamed: IC2.16 (B2), R7.1
unnamed: IC2.15 (B3), R8.1
unnamed: IC2.14 (B4), R9.1
unnamed: IC2.13 (B5), R10.1
unnamed: IC2.12 (B6), R11.1
unnamed: IC2.11 (B7), R12.1
unnamed: J14.1 (VBUS), JP21.1 (A)
unnamed: J18.21, U2.13
unnamed: J18.29, JP17.1 (A)
unnamed: J19.1, JP18.2 (B), R22.2, R23.1, SW3.1 (A)
unnamed: J20.1, R29.1
unnamed: J22.1, U26.13 (H1)
unnamed: J22.2, U26.14 (H2)
unnamed: J22.3, U26.15 (H3)
unnamed: J22.4, U26.16 (H4)
unnamed: J22.5, U26.30 (PC0)
unnamed: J22.6, U26.31 (PC1)
unnamed: J22.7, U26.32 (TIN/PC2)
unnamed: J22.8, JP20.1 (A), U26.33 (PC3/TOUT)
unnamed: J22.9, U26.34 (DMAREQ/PC4)
unnamed: J22.10, U26.35 (PC5/PIRQ)
unnamed: J22.11, U26.36 (PC6/PIACK)
unnamed: J22.12, U26.37 (PC7/TIACK)
unnamed: JP7.2 (C), U13.16 (XIN)
unnamed: JP8.2 (B), U14.19 (~RESET)
unnamed: JP9.3 (B), U16.5 (Q)
unnamed: C4.1, JP10.2 (B), U17.2 (VO)
unnamed: C6.1, JP11.2 (B), U15.3 (VO)
unnamed: JP12.2 (C), U18.K4 (CLK)
unnamed: JP13.2 (C), R18.1
unnamed: JP14.1 (A), U10.14 (IO6)
unnamed: JP15.1 (A), U3.12 (IO8)
unnamed: JP16.2 (B), U2.12
unnamed: JP18.1 (A), Q2.3 (C)
unnamed: JP19.2 (C), U26.40 (CLK)
unnamed: JP22.2 (C), U18.K3 (~IACK)
unnamed: Q1.2 (B), R13.2
unnamed: Q2.2 (B), R24.2
unnamed: U2.1, U2.4
unnamed: U13.9 (RCLK), U13.15 (~BAUDOUT)
unnamed: C2.2, U14.17 (3V3OUT)
unnamed: U16.3 (C), U27.2
unnamed: U16.2 (D), U16.6 (~Q)
unnamed: U16.4 (~S), U27.6
unnamed: R20.1, U18.D10 (~DBEN), U19.19 (CE), U20.19 (CE)
unnamed: R19.1, U18.E9 (~DDIR), U19.1 (A->B), U20.1 (A->B)
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

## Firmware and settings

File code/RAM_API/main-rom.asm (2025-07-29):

    section .vectors
	ORG		$000000
    dc.l   $00001000
    dc.l   _start
	dc.l	_exc_bus_err
	dc.l	_exc_add_err

	dc.l	_exc_illegal
	dc.l	_exc_dev_zero
	dc.l	_exc_err_chk
	dc.l	_exc_overflow
	dc.l	_exc_usr_privilage

	dc.l	_exc_trace
	dc.l	_exc_line1010
	dc.l	_exc_line1111

	dc.l	_exc_soft_none0
	dc.l	_exc_soft_none1
	dc.l	_exc_soft_none2 ;reserved

	dc.l	_exc_soft_none3 ;unitilized int vector

	dc.l	_exc_soft_none4
	dc.l	_exc_soft_none5
	dc.l	_exc_soft_none6
	dc.l	_exc_soft_none7
	dc.l	_exc_soft_none8
	dc.l	_exc_soft_none9
	dc.l	_exc_soft_none10
	dc.l	_exc_soft_none11
	dc.l	_exc_soft_none12

	

	;auto vectors
	dc.l	_autovec_none1	;IRQ 1
	dc.l	_autovec_none2	;IRQ 2
	dc.l	_autovec_none3	;IRQ 3
	dc.l	_autovec_none4	;IRQ 4
	dc.l	_autovec_none5	;IRQ 5 - xosera
	dc.l	_autovec_none6	;IRQ 6
	dc.l	_autovec_none7	;IRQ 7
		
	;TRAP 0-15
	dc.l	_exc_trap_VID		;Xosera
	dc.l	_exc_trap_UART		;UART
	dc.l	_exc_trap_none2	
	dc.l	_exc_trap_none3	
	dc.l	_exc_trap_none4	
	dc.l	_exc_trap_none5	
	dc.l	_exc_trap_none6	
	dc.l	_exc_trap_none7	
	dc.l	_exc_trap_none8	
	dc.l	_exc_trap_none9	
	dc.l	_exc_trap_none10	
	dc.l	_exc_trap_none11	
	dc.l	_exc_trap_none12	
	dc.l	_exc_trap_none13	
	dc.l	_exc_trap_none14	
	dc.l	_exc_trap_none15	

PWR_TRIG		equ 	$FFFFFF
RAM_START		equ     $100000
STACK_START		equ		RAM_START+$1EFF0
program			equ		RAM_START+$1F000
UART_BASE       equ     $FF0000

UART_RBR        equ     $00
UART_THR        equ     $00
UART_IER        equ     $02
UART_IIR        equ     $04
UART_FCR        equ     $04
UART_LCR        equ     $06
UART_MCR        equ     $08
UART_LSR        equ     $0A
UART_MSR        equ     $0C
UART_SCR        equ     $0E

UART_DLL        equ     $00
UART_DLM        equ     $02

DEBUG		equ		1
	section .text

	INCLUDE 	"xmodem.asm"
	INCLUDE		"xosera.asm"
	INCLUDE		"dmac.asm"
	INCLUDE		"PPI_KEYB_PIT.asm"
	INCLUDE		"bss.asm"
	section .text
_start:
	lea		STACK_START,a7	;set up stack
	lea 	UART_BASE,a0
	move.b  #$80,(UART_LCR,a0) ; Enable DLAB
    ; Set divisor latch for 9600 baud
	;move.b  #$78,(UART_DLL,a0) ; 9600 baud @ 18.432 MHz
	move.b  #$0A,(UART_DLL,a0) 	; 115200 baud @ 18.432 MHz
	move.b  #$00,(UART_DLM,a0) 

    ; 8N1, DLAB=0
	move.b  #$03,(UART_LCR,a0)

	;FIFO enable
	move.b 	#$07,(UART_FCR,a0)

	jsr		clear_ram
	;jsr		receve_byte
	;move.w  #$2700,sr	;disable interupts
	jsr		wait_for_x
	jsr		init_xosera	

	jsr		x_update_screen
	jsr		init_DMAC
	jsr		ppi_init
	

	lea		msg,a0
	move	#1,d1		;Xosera MODE 1 - a0 string
	TRAP	#0
	move	#3,d1
	TRAP	#0			;Xosera update screen

	
	lea		program,a0
	jsr		xmodem_receve

.wait:
	
	jsr		receve_byte
	cmp		#13,d0
	bne		.wait
	lea		program,a0
	
	jsr		(a0)		;jump to loaded program
.stop:

	;move.b #$FF,(PWR_TRIG)
	jmp *
clear_ram:	
	lea		RAM_START,a0
	move	#$FFFF/2,d0
.loop:
	move.w	#0,(a0)+
	dbra	d0,.loop
	rts
wait_for_x:	
	move	#$0002,d1
.l1:
	move	#$FFFF,d0
.l2:
	nop
	nop
	nop
	dbra	d0,.l2
	dbra	d1,.l1
	rts
;d1 - MODE
;MODE 0 - d0 - byte to send, MODE 1 - a0 string to send, MODE 2 - halting receve in d0
_exc_trap_UART:
	cmp		#0,d1
	bne		.mode1tst
	jsr		send_byte
	rte
.mode1tst:
	cmp		#1,d1
	bne		.mode2tst
	jsr		send_string
	rte
.mode2tst:
	jsr		receve_byte
	rte
;d0 - data
send_byte:
	movem.l d1/a0,-(a7)           ; Save registers
	lea		UART_BASE,a0
.loop:
	move.b 	(UART_LSR,a0),d1
	btst	#5,d1 ;test bit 5 of d1 register
	beq		.loop ;if 0 loop
	move.b  d0,(UART_BASE)
	movem.l (a7)+,d1/a0           ; Restore registers
	rts

;wait 
receve_byte:
	move.l 	a0,-(a7)           ; Save registers
	lea		UART_BASE,a0
.loop:
	move.b 	(UART_LSR,a0),d0
	btst	#0,d0 ;test bit 5 of d1 register
	beq		.loop ;if 0 loop
	
	move.b  (UART_RBR,a0),d0
	movem.l	(a7)+,a0
	rts

;a0 - string address
send_string:
	movem.l	d0/a1,-(a7)
	lea 	UART_BASE,a1
	
.loop:
	move.b 	(UART_LSR,a1),d0
	btst	#5,d0 	;test bit 5 of d1 register
	beq		.loop 	;if 0 loop
	tst.b	(a0)
	beq		.end	;is 0
	move.b  (a0)+,(UART_THR,a1)
	jmp 	.loop
.end:
	movem.l	(a7)+,d0/a1
	rts

; --------------------------------------------------------------
; print_hex_a0
;  Prints the contents of A0 as an 8-digit hexadecimal number
;  Input : A0 = 32-bit address
;  Clobbers: D0, D1
; --------------------------------------------------------------
print_hex_add:
    movem.l d0-d2/a1,-(a7)      ; Save used registers

    move.l  A0,D1              ; Copy address to D1
    moveq   #8-1,D2            ; Loop 8 times (8 hex digits)

    lea     UART_BASE,A1       ; UART base address

.hex_loop:
	move.l	d1,d0
	lsr.l	#8,d0
	lsr.l	#8,d0
	lsr.l	#8,d0
	lsr.l	#4,d0         		; Shift down to get correct nibble
    andi.b  #$0F,D0            	; Mask single nibble

	lsl.l	#4,d1				;put new nibble to highest nibble

    cmpi.b  #9,D0
    ble     .digit
    addi.b  #'A'-10,D0
    bra     .send
.digit:
    addi.b  #'0',D0
.send:
    jsr     send_byte

    dbra    D2,.hex_loop       ; Loop for all 8 digits

    movem.l (a7)+,d0-d2/a1      ; Restore registers
    rts


test_RAM:
	move	(a7),d7 		;save return address
;safe zone
	move	#0,d0
	move.l	#$100000,d1		;loop
	lea.l		RAM_START,a0
.loop1:						;1M words = 2MB
	move.w	d0,(a0)+
	addq.w	#1,d0
	subq.l	#1,d1
	bne		.loop1

	move	#0,d2
	move.l	#$100000,d1		;loop
	lea.l	RAM_START,a0
.loop2:						;chek loop
	move.w	(a0)+,d0
	cmp.w	d2,d0
	bne		.error
	addq.l	#1,d2
	subq.l	#1,d1
	bne		.loop2

	
	move	d7,(a7)	;return address of return
	lea		msg_OK,a0
	jsr		send_string
	rts
.error:
	move	d7,(a7)	;return address of return

	move	a0,a2
	lea		msg_wrong,a0
	jsr 	send_string
	lea		msg_failed_at,a0
	jsr 	send_string
	move	a2,a0
	jsr 	print_hex_add
	
	rts
_autovec_none:
	move.l	d0,-(a7)
	move	#'X',d0
	jsr		send_byte
	move.l	(a7)+,d0
	rte

_exc_illegal:
	move	d0,-(a7)
	move.b	#'0',d0
	jmp		print_exeption
_exc_bus_err:
	move	d0,-(a7)
	move.b	#'1',d0
	jmp		print_exeption
_exc_add_err:
	move	d0,-(a7)
	move.b	#'2',d0
	jmp		print_exeption
_exc_dev_zero:
	move	d0,-(a7)
	move.b	#'3',d0
	jmp		print_exeption
_exc_err_chk:
	move	d0,-(a7)
	move.b	#'4',d0
	jmp		print_exeption
_exc_overflow:
	move	d0,-(a7)
	move.b	#'5',d0
	jmp		print_exeption
_exc_usr_privilage:
	move	d0,-(a7)
	move.b	#'6',d0
	jmp		print_exeption
_exc_trace:
	move	d0,-(a7)
	move.b	#'7',d0
	jmp		print_exeption
_exc_line1010:
	move	d0,-(a7)
	move.b	#'8',d0
	jmp		print_exeption
_exc_line1111:
	move	d0,-(a7)
	move.b	#'9',d0
	jmp		print_exeption
_exc_soft_none:
	move	d0,-(a7)
	move.b	#'A',d0
	jmp		print_exeption

_exc_soft_none0:
	move	d0,-(a7)
	move.b	#'B',d0
	jmp		print_exeption
_exc_soft_none1:
	move	d0,-(a7)
	move.b	#'C',d0
	jmp		print_exeption
_exc_soft_none2: ;
	move	d0,-(a7)
	move.b	#'D',d0
	jmp		print_exeption
_exc_soft_none3: ;
	move	d0,-(a7)
	move.b	#'E',d0
	jmp		print_exeption
_exc_soft_none4:
	move	d0,-(a7)
	move.b	#'F',d0
	jmp		print_exeption
_exc_soft_none5:
	move	d0,-(a7)
	move.b	#'G',d0
	jmp		print_exeption
_exc_soft_none6:
	move	d0,-(a7)
	move.b	#'H',d0
	jmp		print_exeption
_exc_soft_none7:
	move	d0,-(a7)
	move.b	#'I',d0
	jmp		print_exeption
_exc_soft_none8:
	move	d0,-(a7)
	move.b	#'J',d0
	jmp		print_exeption
_exc_soft_none9:
	move	d0,-(a7)
	move.b	#'K',d0
	jmp		print_exeption
_exc_soft_none10:
	move	d0,-(a7)
	move.b	#'L',d0
	jmp		print_exeption
_exc_soft_none11:
	move	d0,-(a7)
	move.b	#'M',d0
	jmp		print_exeption
_exc_soft_none12:
	move	d0,-(a7)
	move.b	#'N',d0
	jmp		print_exeption


_exc_trap_none1:
	move	d0,-(a7)
	move.b	#'O',d0
	jmp		print_exeption
_exc_trap_none2:
	move	d0,-(a7)
	move.b	#'P',d0
	jmp		print_exeption
_exc_trap_none3:
	move	d0,-(a7)
	move.b	#'R',d0
	jmp		print_exeption
_exc_trap_none6:
	move	d0,-(a7)
	move.b	#'S',d0
	jmp		print_exeption
_exc_trap_none7:
	move	d0,-(a7)
	move.b	#'T',d0
	jmp		print_exeption

_exc_trap_none0:	
	move	d0,-(a7)
	move.b	#'U',d0
	jmp		print_exeption
_exc_trap_none4:	
	move	d0,-(a7)
	move.b	#'Q',d0
	jmp		print_exeption
_exc_trap_none5:	
	move	d0,-(a7)
	move.b	#'a',d0
	jmp		print_exeption
_exc_trap_none8:	
	move	d0,-(a7)
	move.b	#'d',d0
	jmp		print_exeption
_exc_trap_none9:	
	move	d0,-(a7)
	move.b	#'e',d0
	jmp		print_exeption
_exc_trap_none10:
	move	d0,-(a7)
	move.b	#'f',d0
	jmp		print_exeption
_exc_trap_none11:
	move	d0,-(a7)
	move.b	#'g',d0
	jmp		print_exeption
_exc_trap_none12:
	move	d0,-(a7)
	move.b	#'h',d0
	jmp		print_exeption
_exc_trap_none13:
	move	d0,-(a7)
	move.b	#'i',d0
	jmp		print_exeption
_exc_trap_none14:
	move	d0,-(a7)
	move.b	#'j',d0
	jmp		print_exeption
_exc_trap_none15:
	move	d0,-(a7)
	move.b	#'k',d0
	jmp		print_exeption
_autovec_none1:
	move	d0,-(a7)
	move.b	#'l',d0
	jmp		print_exeption
_autovec_none2:
	move	d0,-(a7)
	move.b	#'m',d0
	jmp		print_exeption
_autovec_none3:
	move	d0,-(a7)
	move.b	#'n',d0
	jmp		print_exeption
_autovec_none4:
	move	d0,-(a7)
	move.b	#'o',d0
	jmp		print_exeption
_autovec_none5:
	move	d0,-(a7)
	move.b	#'p',d0
	jmp		print_exeption
_autovec_none6:
	move	d0,-(a7)
	move.b	#'r',d0
	jmp		print_exeption
_autovec_none7:
	move	d0,-(a7)
	move.b	#'s',d0
	jmp		print_exeption
print_exeption:
	jsr	send_byte
	move	(a7)+,d0
	
	rte


	section .rodata
msg:
	dc.b 13,"Hello form 68k!",13,10,0

msg_wrong:
	dc.b 13,"Memory test FAIL",13,10,0
msg_failed_at:
	dc.b 13,"Failed at 0x",0

msg_OK:
	dc.b 13,"Memory test OK",13,10,0

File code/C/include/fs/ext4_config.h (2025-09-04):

/*
 * Copyright (c) 2013 Grzegorz Kostka (kostka.grzegorz@gmail.com)
 * All rights reserved.
 *
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
 * - Redistributions of source code must retain the above copyright
 *   notice, this list of conditions and the following disclaimer.
 * - Redistributions in binary form must reproduce the above copyright
 *   notice, this list of conditions and the following disclaimer in the
 *   documentation and/or other materials provided with the distribution.
 * - The name of the author may not be used to endorse or promote products
 *   derived from this software without specific prior written permission.
 *
 * THIS SOFTWARE IS PROVIDED BY THE AUTHOR ``AS IS'' AND ANY EXPRESS OR
 * IMPLIED WARRANTIES, INCLUDING, BUT NOT LIMITED TO, THE IMPLIED WARRANTIES
 * OF MERCHANTABILITY AND FITNESS FOR A PARTICULAR PURPOSE ARE DISCLAIMED.
 * IN NO EVENT SHALL THE AUTHOR BE LIABLE FOR ANY DIRECT, INDIRECT,
 * INCIDENTAL, SPECIAL, EXEMPLARY, OR CONSEQUENTIAL DAMAGES (INCLUDING, BUT
 * NOT LIMITED TO, PROCUREMENT OF SUBSTITUTE GOODS OR SERVICES; LOSS OF USE,
 * DATA, OR PROFITS; OR BUSINESS INTERRUPTION) HOWEVER CAUSED AND ON ANY
 * THEORY OF LIABILITY, WHETHER IN CONTRACT, STRICT LIABILITY, OR TORT
 * (INCLUDING NEGLIGENCE OR OTHERWISE) ARISING IN ANY WAY OUT OF THE USE OF
 * THIS SOFTWARE, EVEN IF ADVISED OF THE POSSIBILITY OF SUCH DAMAGE.
 */

/** @addtogroup lwext4
 * @{
 */
/**
 * @file  ext4_config.h
 * @brief Configuration file.
 */

#ifndef EXT4_CONFIG_H_
#define EXT4_CONFIG_H_

#ifdef __cplusplus
extern "C" {
#endif

#if !CONFIG_USE_DEFAULT_CFG
//#include "generated/ext4_config.h"
#endif

/*****************************************************************************/

#define F_SET_EXT2 2
#define F_SET_EXT3 3
#define F_SET_EXT4 4

#ifndef CONFIG_EXT_FEATURE_SET_LVL
#define CONFIG_EXT_FEATURE_SET_LVL F_SET_EXT2
#endif

/*****************************************************************************/

#if CONFIG_EXT_FEATURE_SET_LVL == F_SET_EXT2
/*Superblock features flag EXT2*/
#define CONFIG_SUPPORTED_FCOM EXT2_SUPPORTED_FCOM
#define CONFIG_SUPPORTED_FINCOM (EXT2_SUPPORTED_FINCOM | EXT_FINCOM_IGNORED)
#define CONFIG_SUPPORTED_FRO_COM EXT2_SUPPORTED_FRO_COM

#elif CONFIG_EXT_FEATURE_SET_LVL == F_SET_EXT3
/*Superblock features flag EXT3*/
#define CONFIG_SUPPORTED_FCOM EXT3_SUPPORTED_FCOM
#define CONFIG_SUPPORTED_FINCOM (EXT3_SUPPORTED_FINCOM | EXT_FINCOM_IGNORED)
#define CONFIG_SUPPORTED_FRO_COM EXT3_SUPPORTED_FRO_COM
#elif CONFIG_EXT_FEATURE_SET_LVL == F_SET_EXT4
/*Superblock features flag EXT4*/
#define CONFIG_SUPPORTED_FCOM EXT4_SUPPORTED_FCOM
#define CONFIG_SUPPORTED_FINCOM (EXT4_SUPPORTED_FINCOM | EXT_FINCOM_IGNORED)
#define CONFIG_SUPPORTED_FRO_COM EXT4_SUPPORTED_FRO_COM
#else
#define "Unsupported CONFIG_EXT_FEATURE_SET_LVL"
#endif

#define CONFIG_DIR_INDEX_ENABLE (CONFIG_SUPPORTED_FCOM & EXT4_FCOM_DIR_INDEX)
#define CONFIG_EXTENT_ENABLE (CONFIG_SUPPORTED_FINCOM & EXT4_FINCOM_EXTENTS)
#define CONFIG_META_CSUM_ENABLE (CONFIG_SUPPORTED_FRO_COM & EXT4_FRO_COM_METADATA_CSUM)

/*****************************************************************************/

/**@brief  Enable/disable journaling*/
#ifndef CONFIG_JOURNALING_ENABLE
#define CONFIG_JOURNALING_ENABLE 0
#endif

/**@brief  Enable/disable xattr*/
#ifndef CONFIG_XATTR_ENABLE
#define CONFIG_XATTR_ENABLE 0
#endif

/**@brief  Enable/disable extents*/
#ifndef CONFIG_EXTENTS_ENABLE
#define CONFIG_EXTENTS_ENABLE 1
#endif

/**@brief   Include error codes from ext4_errno or standard library.*/
#ifndef CONFIG_HAVE_OWN_ERRNO
#define CONFIG_HAVE_OWN_ERRNO 0
#endif

/**@brief   Debug printf enable (stdout)*/
#ifndef CONFIG_DEBUG_PRINTF
#define CONFIG_DEBUG_PRINTF 1
#endif

/**@brief   Assert printf enable (stdout)*/
#ifndef CONFIG_DEBUG_ASSERT
#define CONFIG_DEBUG_ASSERT 1
#endif

/**@brief   Include assert codes from ext4_debug or standard library.*/
#ifndef CONFIG_HAVE_OWN_ASSERT
#define CONFIG_HAVE_OWN_ASSERT 1
#endif

/**@brief   Statistics of block device*/
#ifndef CONFIG_BLOCK_DEV_ENABLE_STATS
#define CONFIG_BLOCK_DEV_ENABLE_STATS 1
#endif

/**@brief   Cache size of block device.*/
#ifndef CONFIG_BLOCK_DEV_CACHE_SIZE
#define CONFIG_BLOCK_DEV_CACHE_SIZE 32
#endif


/**@brief   Maximum block device name*/
#ifndef CONFIG_EXT4_MAX_BLOCKDEV_NAME
#define CONFIG_EXT4_MAX_BLOCKDEV_NAME 32
#endif


/**@brief   Maximum block device count*/
#ifndef CONFIG_EXT4_BLOCKDEVS_COUNT
#define CONFIG_EXT4_BLOCKDEVS_COUNT 2
#endif

/**@brief   Maximum mountpoint name*/
#ifndef CONFIG_EXT4_MAX_MP_NAME
#define CONFIG_EXT4_MAX_MP_NAME 32
#endif

/**@brief   Maximum mountpoint count*/
#ifndef CONFIG_EXT4_MOUNTPOINTS_COUNT
#define CONFIG_EXT4_MOUNTPOINTS_COUNT 2
#endif

/**@brief   Include open flags from ext4_errno or standard library.*/
#ifndef CONFIG_HAVE_OWN_OFLAGS
#define CONFIG_HAVE_OWN_OFLAGS 1
#endif
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

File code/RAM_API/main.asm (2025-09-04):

PWR_TRIG		equ 	$FFFFFF
RAM_START		equ     $100000
STACK_START		equ		RAM_START+$10000
UART_BASE       equ     $FF0000

UART_RBR        equ     $00
UART_THR        equ     $00
UART_IER        equ     $02
UART_IIR        equ     $04
UART_FCR        equ     $04
UART_LCR        equ     $06
UART_MCR        equ     $08
UART_LSR        equ     $0A
UART_MSR        equ     $0C
UART_SCR        equ     $0E

UART_DLL        equ     $00
UART_DLM        equ     $02

	section .text
;DEBUG
DEBUG	equ		0
CHK_SIZE	equ		65536

API_PRINT_BYTE		equ		$00
API_PRINT_WORD		equ		$01
API_SEND_BYTE		equ		$02
API_PRINT_STR_BYTE	equ		$03
API_PRINT_STR_WORD	equ		$04
API_SEND_STR		equ		$05
API_GET_CURSOR_XY	equ		$06
API_SET_CURSOR_XY	equ		$07

prog_start 	equ	RAM_START+$30000	;lots of space

; Macro to disable all maskable interrupts by setting IPL = 7
    macro STI
    move.w  #$2700,sr    ; Disable all interrupts (IPL=7), Supervisor mode on
    endm

; Macro to enable all interrupts by clearing IPL to 0
    macro CLI
    move.w  #$2200,sr    ; Enable all interrupts (IPL=0), Supervisor mode on
    endm

_start:	
	bsr		ppi_init
	bsr		init_traps
	bsr		init_tmr

	STI


	
	lea		msg_press_enter,a0
	move	#3,d1
	bsr		x_print_byte_string
	;TRAP	#0
	STI
.l:
	bsr		kyb_get_key
	;cmp.b	#10,d0
	;bne		.l
	;bsr		x_print_char_byte
	lea		prog_start,a0
	bsr		xmodem_receve
	;bsr		kyb_get_key
	lea		prog_start,a0
	jsr		(a0)
	jmp		.l



;Set trap to subrutine
init_traps:
	lea		_exc_trap_0,a1
	lea		TRAP0_handler,a0
	move.l	a0,(a1)+	;TRAP #1
	lea		TRAP_empty,a0
	move.l	a0,(a1)+	;TRAP #2
	move.l	a0,(a1)+	;TRAP #3
	move.l	a0,(a1)+	;TRAP #4
	move.l	a0,(a1)+	;TRAP #5
	move.l	a0,(a1)+	;TRAP #6
	move.l	a0,(a1)+	;TRAP #7
	move.l	a0,(a1)+	;TRAP #8
	move.l	a0,(a1)+	;TRAP #9
	move.l	a0,(a1)+	;TRAP #10
	move.l	a0,(a1)+	;TRAP #11
	move.l	a0,(a1)+	;TRAP #12
	move.l	a0,(a1)+	;TRAP #13
	move.l	a0,(a1)+	;TRAP #14
	move.l	a0,(a1)+	;TRAP #15
	
	rts
;	Desc			D1		  D0			D2			A0			A1
;	Print char		$0		(byte)			XX			XX			XX
;	Print char		$1		(word)			XX			XX			XX
;	Send byte		$2		(byte)			XX			XX			XX
;	Print string	$3		  XX			XX		STR(byte)		XX
;	Print string	$4		  XX			XX		STR(word)		XX
;	Send string		$5		  XX			XX		STR(byte)		XX
;	Get cursor X,Y	$6	   (X,word)		 (Y,word)		XX			XX
;	Set cursor X,Y	$7	   (X,word)		 (Y,word)		XX			XX
;	Get key			$8		(byte)			XX			XX			XX
;	Peek key		$9	  (byte or 0)		XX			XX			XX
;	Scroll up by d0	$A		(word)			XX			XX			XX
;	Read sectors	$B (1st sector LBA)(sector cnt)	   PTR			XX
;	Write sectors	$C (1st sector LBA)(sector cnt)	   PTR			XX

TRAP0_handler:
	STI
	move.l	a7,(_stack_tmp)
	lea  	_sys_stack_start,a7

	cmp.b	#$0,d1
	bne		.s0
	;Print char (byte)
	bsr		x_print_char_byte
.s0:
	cmp.b	#$1,d1
	bne		.s1
	;Print char (word)
	bsr		x_print_char_word
.s1:
	cmp.b	#$2,d1
	bne		.s2
	;Send byte
	bsr		send_byte
.s2:
	cmp.b	#$3,d1
	bne		.s3
	;Print string (byte)
	bsr		x_print_byte_string
.s3:
	cmp.b	#$4,d1
	bne		.s4
	;Print string (word)
	bsr		x_print_word_string
.s4:
	cmp.b	#$5,d1
	bne		.s5
	;Send string (byte)
	bsr		send_string
.s5:
	cmp.b	#$6,d1
	bne		.s6
	;Get cursor X/Y (word, word)
	bsr		x_get_cursor_xy
	move.w	d1,d2	;Y
	jmp		.end
.s6:
	cmp.b	#$7,d1
	bne		.s7
	;Set cursor X/Y (word, word)
	move.w	d2,d1	;Y
	bsr		x_set_cursor_xy
	jmp		.end
.s7:
	cmp.b	#$8,d1
	bne		.s8
	;Chek key (1 or 0)
	CLI ;We dont want a halt of cursor
	bsr		kyb_get_key
	jmp		.end
.s8:
	cmp.b	#$9,d1
	bne		.s9
	;Read sectors (byte cnt)
	bsr		kyb_get_key_current
	jmp		.end
.s9:
	cmp.b	#$A,d1
	bne		.sA
	;scroll up by d0 (byte cnt)
	bsr		screen_scroll
	jmp		.end
.sA:
	cmp.b	#$B,d1
	bne		.sB
	;scroll up by d0 (byte cnt)
	bsr		x_get_cursor_xy
	jmp		.end
.sB:
	cmp.b	#$C,d1
	bne		.sC
	;d0 -Y/X
	;set xy d0 - x d1 - y
	swap	d0
	move.w	d0,d1
	swap	d0
	and.l	#$0000FFFF,d0
	bsr		x_set_cursor_xy
	jmp		.end
.sC:
	cmp.b	#$D,d1
	bne		.sD
	;write sector
	;D0 - LBA d2 - cnt
	
	move.l	d2,d1;cnt
	move.w	#1,d0
	move.w	#1,d1
	bsr		IDE_write_sectors_LBA
	lea		msg_done,a0
	bsr		x_print_byte_string
	jmp		.end
.sD:
	cmp.b	#$E,d1
	bne		.sE
	;read sector
	;D0 - LBA d2 - cnt
	;jmp		.end
	move.l	d2,d1;cnt
	bsr		IDE_read_sectors_LBA
	lea		msg_done,a0
	bsr		x_print_byte_string
	jmp		.end
.sE:
	cmp.b	#$F,d1
	bne		.sF
	;Print byte buffer with lenght in d0, ptr in a0
	bsr		x_print_byte_buffer
	jmp		.end
.sF:
	cmp.b	#$10,d1
	bne		.s10
	bsr		receve_byte
	jmp		.end
.s10:
	cmp.b	#$11,d1
	bne		.s11
	bsr		peek_byte
	jmp		.end
.s11:
	cmp.b	#$12,d1
	bne		.s12
	move.l	(tmr_cnt),d0
	jmp		.end
.s12:
	cmp.b	#$13,d1
	bne		.s13
	;Uart receve block d0.w bytes
	CLI ;needed
	move.w	d0,d1
	move.l	(tmr_cnt),d2
	add.l	#100,d2
.13l:
	cmp.l	(tmr_cnt),d2
	beq		.end
	;move.b 	(UART_LSR+UART_BASE),d0
	btst	#0,d0 ;test bit 5 of d1 register
	beq		.13l ;if 0 loop
	move.b  (UART_RBR+UART_BASE),d0
	move.b	d0,(a0)+
	dbra	d1,.13l
	jmp		.end
.s13:
	cmp.b	#$14,d1
	bne		.s14
	;Print word buffer with lenght in d0, ptr in a0
	bsr		x_print_word_buffer
	jmp		.end
.s14
.end:
	move.l	(_stack_tmp),a7
	;CLI
	rte

TRAP_empty:	
	movem.l	d0/a0,-(a7)
	lea		msg_empty_trap,a0
	bsr		send_string
	lea		msg_empty_trap,a0
	bsr		x_print_byte_string
	movem.l (a7)+,d0/a0
	rte
msg:
	dc.b "Hello form 68k! in RAM",13,10,0
	align 2
msg_w:
	dc.w $0F41,$0F42,$0F43,$0A41,$0D41,10,13,0
msg_done:
	dc.B	13,10,"DONE!",13,10,0
msg_wrong:
	dc.b 13,"Memory test FAIL",13,10,0
msg_failed_at:
	dc.b 13,"Failed at 0x",0
msg_drv_err:
	dc.b 13,"Drive error 0x",0
msg_OK:
	dc.b 13,10,"Memory test OK",13,10,0
msg_chk:
	dc.b 13,"Checking...  "
	align 2
msg_illegal_w:
	dc.w $0450,$0441,$044E,$0449,$0443,$0420,$047C,$0420,$0449,$046C,$046C,$0465,$0467,$0461,$046C,$0420,$0469,$046E,$0473,$0474,$0472,$0475,$0463,$0474,$0469,$046F,$046E,$0000
msg_illegal:
	dc.b "PANIC | Illegal instruction"
msg_add_err:
	dc.b 13,10,"PANIC | Address error!",0
msg_add_err_w
	dc.w $0450,$0441,$044E,$0449,$0443,$0420,$047C,$0420,$0441,$0464,$0464,$0472,$0465,$0473,$0473,$0420,$0465,$0472,$0472,$046F,$0472,$0421,$0400
msg_press_enter:
	dc.b 13,10,"Press ENTER key ...",0
msg_empty_trap:
	dc.b 13,10,"Empty TRAP",0
	align	4

	align 4
	INCLUDE		"UART.asm"
	INCLUDE		"xosera.asm"
	INCLUDE		"xmodem.asm"
	INCLUDE		"PPI_KEYB_PIT.asm"
	INCLUDE		"IDE.asm"
	INCLUDE		"../common/bss.asm"

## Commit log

2025-07-31 Full keyboard implemented with some special keys, print now uses NL, BS etc and fixed cursor, PANIC for illigal and address error
    [main.asm]
2025-08-01 Started newlib port
    [gvmat32.obj, gvmat64.obj, inffas32.obj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]
2025-08-01 newlib try 2
    [gvmat32.obj, gvmat64.obj, inffas32.obj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]
2025-08-03 Working printf and string stuff, but doesnt work on first load - init error?
    [amix_sys.c, main.asm]
2025-08-04 Added scrooling sometimes bugy when clear, and something like shell for testing
    [amix_sys.c, main.asm]
2025-08-17 fixed exc to show correct address
    [main.c]
2025-08-25 Added ability to change text colors but is glitchy, will branch to try to make processes
    [main.asm]
2025-08-28 Added cathcer to chach crashes and terminate process that crashed
    [main.c]

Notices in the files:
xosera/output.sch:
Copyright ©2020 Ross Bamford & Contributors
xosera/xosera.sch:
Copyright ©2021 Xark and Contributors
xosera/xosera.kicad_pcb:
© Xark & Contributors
